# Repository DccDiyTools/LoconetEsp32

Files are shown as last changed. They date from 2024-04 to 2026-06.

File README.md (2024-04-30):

# LoconetEsp32
Esp32 Loconet Interface
# LocoBuffer from LocoLinx32U4

Board for use wiht the [https://github.com/mrrwa/LocoNet/tree/master/examples/LocoLinx32U4] code, there is a copy on this repository for platform.io .

# 0.0.1
- [x] USB
- [x] Loconet
- [x] Leds loconet
- [x] ESP32
- [ ] Btn Reset

# 0.0.X
- [] Loconet Power 
- [] Loconet Master
- [] USB-C
- [] Non-Inv TX
- [] SD
- [] BTN AP
- [] Led Wifi RGB

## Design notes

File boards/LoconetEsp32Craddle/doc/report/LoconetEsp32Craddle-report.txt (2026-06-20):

# PCB

Board size: 95.0x71.0 mm (3.74x2.8 inches)

- This is the size of the rectangle that contains the board
- Thickness: 1.6 mm (63 mils)
- Material: FR4
- Finish: None
- Layers: 4
- Copper thickness: 35 µm

Solder mask: TOP / BOTTOM

- Color: Green

Silk screen: TOP / BOTTOM

- Color: White

Stackup:

| Name | Type | Color | Thickness [µm]| Material | Er | Loss tan |
|---|---|---|---|---|---|---|
| F.SilkS | Top Silk Screen | | | | | |
| F.Paste | Top Solder Paste | | | | | |
| F.Mask | Top Solder Mask | | 10 | | | |
| F.Cu | copper | | 35 | | | |
| dielectric 1 | core | | 480 | FR4 | 4.5 | 0.020 |
| In1.Cu | copper | | 35 | | | |
| dielectric 2 | prepreg | | 480 | FR4 | 4.5 | 0.020 |
| In2.Cu | copper | | 35 | | | |
| dielectric 3 | core | | 480 | FR4 | 4.5 | 0.020 |
| B.Cu | copper | | 35 | | | |
| B.Mask | Bottom Solder Mask | | 10 | | | |
| B.Paste | Bottom Solder Paste  | | | | | |
| B.SilkS | Bottom Silk Screen | | | | | |

# Important sizes

Clearance: 0.2 mm (8 mils)

Track width: 0.25 mm (10 mils)

- By design rules: 0.2 mm (8 mils)

Drill: 0.5 mm (20 mils)

- Vias: 0.5 mm (20 mils) [Design: 0.3 mm (12 mils)]
- Pads: 0.9 mm (35 mils)
- The above values are real drill sizes, they add 0.1 mm (4 mils) to plated holes (PTH)

Via: 0.8/0.4 mm (31/16 mils)

- By design rules: 0.2/0.2 mm (8/8 mils)
- Micro via: yes [0.2/0.1 mm (8/4 mils)]
- Buried/blind via: yes
- Total: 22 (thru: 22 buried/blind: 0 micro: 0)

Outer Annular Ring: 0.15 mm (6 mils)

- By design rules: 0.15 mm (6 mils)

Eurocircuits class: 4B
- Using min drill 0.5 mm for an OAR of 0.15 mm

# General stats

Components count: (SMD/THT)

- Top: 43/8 (SMD + THT)
- Bottom: 0/2 (THT)

Defined tracks:

Used tracks:

- 0.25 mm (10 mils) (153) defined: no
- 0.4 mm (16 mils) (73) defined: no

Defined vias:

Used vias:

- 0.8/0.4 mm (31/16 mils) (Count: 22, Aspect: 2.0 A) defined: no

Holes (excluding vias):

- 0.8 mm (31 mils) (38)
- 0.89 mm (35 mils) (12)
- 1.0 mm (39 mils) (4)
- 3.2 mm (126 mils) (4)
- 3.45 mm (136 mils) (4)

Oval holes:

Drill tools (including vias and computing adjusts and rounding):

- 0.5 mm (20 mils) (22)
- 0.9 mm (35 mils) (38)
- 1.0 mm (39 mils) (12)
- 1.1 mm (43 mils) (4)
- 3.3 mm (130 mils) (4)
- 3.45 mm (136 mils) (4)

Solder paste stats:

Using a paste with 87.75 % alloy, that has an specific gravity for the alloy of 7.4 g/cm³
and 1.0 g/cm³ for the flux. This paste has an specific gravity of  4.15 g/cm³.

The stencil thickness is  0.12 mm.

| Side | Pads with paste | Area [mm²] | Paste [g] |
|---|---|---|---|
| Total  | 106 | 339.67 | 1.69 |

Note: this is just an approximation to the theoretical value. Margins of the solder mask and waste aren't computed.

# Schematic

Exports the Schematic to the most common exhange format. Suitable for printing. page 1

Exports the Schematic to the most common exhange format. Suitable for printing. page 2

Exports the Schematic to the most common exhange format. Suitable for printing. page 3

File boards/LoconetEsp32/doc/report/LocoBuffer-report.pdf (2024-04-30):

## PCB

Board size: 75.0x50.0 mm (2.95x1.97 inches)

- This is the size of the rectangle that contains the board
- Thickness: 1.6 mm (63 mils)
- Material: FR4
- Finish: None
- Layers: 4
- Copper thickness: 35 µm

Solder mask: TOP / BOTTOM

- Color: Green

Silk screen: TOP / BOTTOM

- Color: White

Stackup:

Name | Type | Color | Thickness | Material | Epsilon_r | Loss tangent
F.SilkS | Top Silk Screen
F.Paste | Top Solder Paste
F.Mask | Top Solder Mask | | 10
F.Cu | copper | | 35
dielectric 1 | core | | 480 | FR4 | 4.5 | 0.020
In1.Cu | copper | | 35
dielectric 2 | prepreg | | 480 | FR4 | 4.5 | 0.020
In2.Cu | copper | | 35
dielectric 3 | core | | 480 | FR4 | 4.5 | 0.020
B.Cu | copper | | 35
B.Mask | Bottom Solder Mask | | 10
B.Paste | Bottom Solder Paste
B.SilkS | Bottom Silk Screen

## Important sizes

Clearance: 0.2 mm (8 mils)

Track width: 0.2 mm (8 mils)

- By design rules: 0.2 mm (8 mils)

Drill: 0.3 mm (12 mils)

- Vias: 0.5 mm (20 mils) [Design: 0.3 mm (12 mils)]
- Pads: 0.3 mm (12 mils)

1

- The above values are real drill sizes, they add 0.1 mm (4 mils) to plated holes (PTH)

Via: 0.8/0.4 mm (31/16 mils)

- By design rules: 0.2/0.2 mm (8/8 mils)
- Micro via: yes [0.2/0.1 mm (8/4 mils)]
- Buried/blind via: yes
- Total: 28 (thru: 28 buried/blind: 0 micro: 0)

Outer Annular Ring: 0.15 mm (6 mils)

- By design rules: 0.15 mm (6 mils)

Eurocircuits class: 4D - Using min drill 0.3 mm for an OAR of 0.15 mm

## General stats

Components count: (SMD/THT)

- Top: 46/2 (SMD + THT)
- Bottom: 0/0 (NONE)

Defined tracks:

Used tracks:

- 0.2 mm (8 mils) (32) defined: no
- 0.25 mm (10 mils) (218) defined: no

Defined vias:

Used vias:

- 0.8/0.4 mm (31/16 mils) (Count: 28, Aspect: 2.0 A) defined: no

Holes (excluding vias):

- 0.2 mm (8 mils) (12)
- 0.89 mm (35 mils) (12)
- 3.2 mm (126 mils) (4)
- 3.45 mm (136 mils) (4)

Oval holes:

- 0.5x1.2 mm (20x47 mils) (2)

Drill tools (including vias and computing adjusts and rounding):

- 0.3 mm (12 mils) (12)
- 0.5 mm (20 mils) (28)
- 0.6 mm (24 mils) (2)
- 1.0 mm (39 mils) (12)
- 3.3 mm (130 mils) (4)

2

- 3.45 mm (136 mils) (4)

3

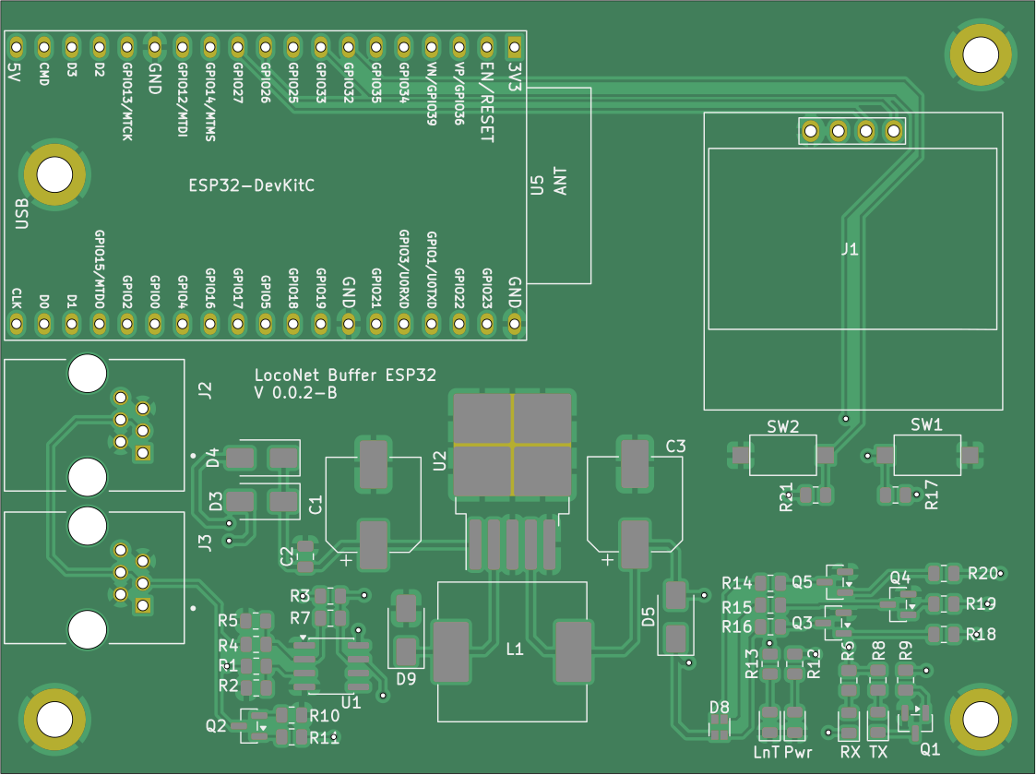
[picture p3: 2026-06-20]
boards/LoconetEsp32Craddle/doc/LoconetEsp32Craddle-top.png

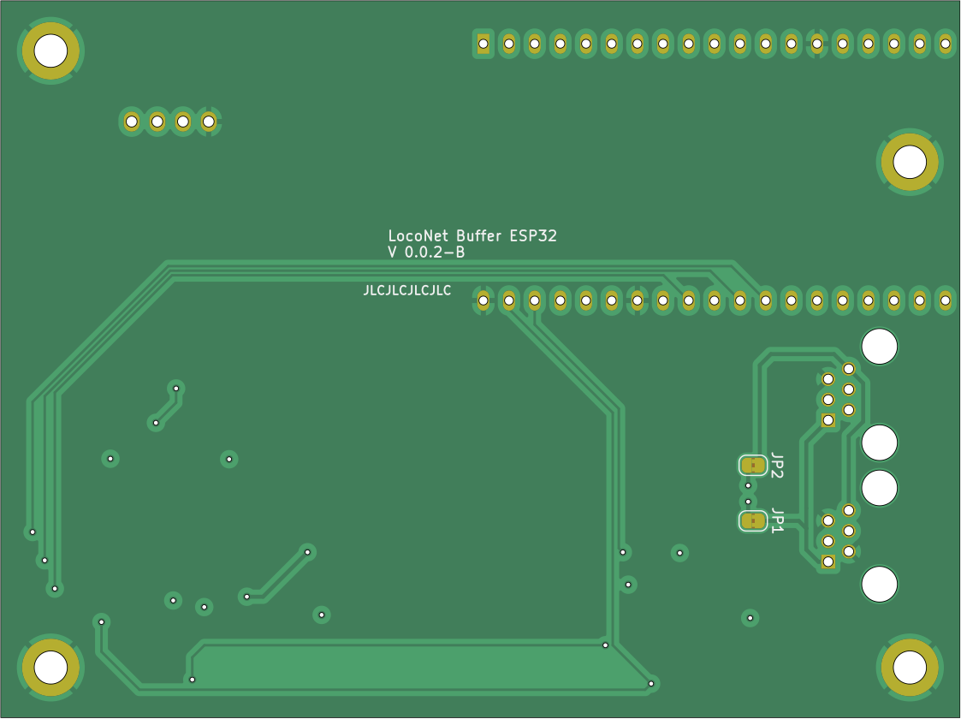
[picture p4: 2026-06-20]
boards/LoconetEsp32Craddle/doc/LoconetEsp32Craddle-bottom.png

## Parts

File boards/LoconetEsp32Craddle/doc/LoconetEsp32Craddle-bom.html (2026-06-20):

 | Bill of Materials
 | Schematic: LoconetEsp32Craddle Variant: default Revision: 0.0.1 Date: 2023-07-17 KiCad Version: 10.0.1-10.0.1~ubuntu25.10.1 | Component Groups: 24 Component Count: 47 (43 SMD/ 4 THT) (per PCB) Fitted Components: 47 (43 SMD/ 4 THT) (per PCB) Number of PCBs: 1 Total Components: 47 (for 1 PCBs)
Row | Description | Part | References | Value | Footprint | Quantity Per PCB | Status | Datasheet | LCSC | Sim.Pins | Sim.Device
1 |  | C | C2 | 100nf | C_0805_2012Metric | 1 |  |  | C282732
2 |  | C_Polarized | C1 C3 | 220uF | CP_Elec_8x10.5 | 2 |  |  | C131124
3 |  | B330 | D9 | B330A | D_SMA | 1 |  | http://www.jameco.com/Jameco/Products/ProdDS/1538777.pdf | C110485
4 | Light emitting diode | LED | D1 D2 D6 D7 | LED | LED_0805_2012Metric | 4 |  |  | C2296 | 1=K 2=A
5 |  | LED_RGBA | D8 | LTST-C19HE1WT | LED_LiteOn_LTST-C19HE1WT | 1 |  |  | C458749
6 |  | D | D3 D4 D5 | SS24A | D_SMA | 3 |  |  | C95872 | 1=K 2=A | D
7 | RJ connector, 6P6C (6 positions 6 connected) | RJ12 | J2 J3 | RJ12 | RJ12_AMPHENOL_RJE0166001 | 2
8 | SSD1306 OLED module, 0.91 inch, 128x32, I2C | ER_OLEDM0.91_1x-I2C | J1 | SD1306 I2C/Oled | ER_OLEDM0.91_1x-I2C-128x64OLED | 1 |  | https://www.buydisplay.com/download/manual/ER-OLEDM0.91-1_Datasheet.pdf
9 |  | L | L1 | 100uH | L_Sunlord_MWSA1206S-101 | 1 |  |  | C408533
10 | 0.115A Id, 60V Vds, N-Channel MOSFET, SOT-23 | 2N7002 | Q3 Q4 Q5 | 2N7002 | SOT-23 | 3 |  | https://www.onsemi.com/pub/Collateral/NDS7002A-D.PDF | C8545
11 | General Purpose NPN Transistor, 1.5A Ic, 25V Vce, SOT-23 | SS8050 | Q1 Q2 | SS8050 | SOT-23 | 2 |  | http://www.secosgmbh.com/datasheet/products/SSMPTransistor/SOT-23/SS8050.pdf | C2150 | 1=B 2=E 3=C | NPN
12 |  | R | R10 | 47 | R_0805_2012Metric | 1 |  |  | C17714
13 |  | R | R6 R8 R12 R13 R14 R15 R16 | 470 | R_0805_2012Metric | 7 |  |  | C17710
14 |  | R | R3 R18 R19 R20 | 1K | R_0805_2012Metric | 4 |  |  | C17513
15 |  | R | R9 R11 | 4.7K | R_0805_2012Metric | 2 |  |  | C229219
16 |  | R | R2 | 22K | R_0805_2012Metric | 1 |  |  | C17560
17 |  | R | R4 | 47K | R_0805_2012Metric | 1 |  |  | C17713
18 |  | R | R5 | 150K | R_0805_2012Metric | 1 |  |  | C17470
19 |  | R | R7 | 220K | R_0805_2012Metric | 1 |  |  | C17556
20 |  | R | R1 R17 R21 | 10K (5%) | R_0805_2012Metric | 3 |  |  | C17414
21 |  | SW_Push | SW1 SW2 | SW_Push | SW_SPST_CK_RS282G05A3 | 2
22 | Development Kit | ESP32-DevKitC | U5 | ESP32-DevKitC | ESP32-DevKitC | 1 |  | https://docs.espressif.com/projects/esp-idf/zh_CN/latest/esp32/hw-reference/esp32/get-started-devkitc.html
23 |  | LM2576S-5 | U2 | LM2576S-5 | TO-263-5_TabPin3 | 1 |  | http://www.ti.com/lit/ds/symlink/lm2576.pdf | C194472
24 |  | LM311 | U1 | LM311 | SOIC-8_3.9x4.9mm_P1.27mm | 1 |  | http://www.ti.com/lit/ds/symlink/lm311.pdf | C12597
Color reference for columns:
KiCad Fields (default)
Generated Fields
User Fields
Empty Fields

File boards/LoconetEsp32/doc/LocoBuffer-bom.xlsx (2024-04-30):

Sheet: BoM
 |  | Bill of Materials
 |  | Schematic: | LocoBuffer | Component Groups: | 27
 |  | Variant: | default | Component Count: | 48 (46 SMD/ 2 THT)
 |  | Revision: |  | Fitted Components: | 48 (46 SMD/ 2 THT)
 |  | Date: | 2023-06-21_17-03-44 | Number of PCBs: | 1
 |  | KiCad Version: | 7.0.5.1-1-g8f565ef7f0-dirty-deb11 | Total Components: | 48
Row | Description | Part | References | Value | Footprint | Quantity Per PCB | Status | Datasheet | LCSC | PARTREV | MANUFACTURER | MAXIMUM_PACKAGE_HEIGHT | STANDARD
1 | Unpolarized capacitor | C | C4 C5 C6 C7 | 0.1uF/50V(10%) | C_0805_2012Metric | 4 |  | ~ | C49678
2 | Unpolarized capacitor | C | C1 C2 | 22uf/10V/20% | C_0805_2012Metric | 2 |  | ~ | C45783
3 | Unpolarized capacitor | C | C3 | 4.7uF/6.3V(10%) | C_0805_2012Metric | 1 |  | ~ | C1779
4 | Schottky diode | D_Schottky | D3 | BAT760-7 | D_SOD-323 | 1 |  | ~ | C124187
5 | Light emitting diode | LED | D1 D2 D7 | LED | LED_0805_2012Metric | 3 |  | ~ | C2296
6 | Bidirectional transient-voltage-suppression diode | D_TVS | D4 D5 D6 | LESD5D5.0CT1G | D_SOD-523 | 3 |  | ~ | C383211
7 |  | 10118193-0001LF | J1 | 10118193-0001LF | AMPHENOL_10118193-0001LF | 1 |  | ~ | C132562 | E | Amphenol FCI | 2.55 mm | Manufacturer Recommendations
8 | RJ connector, 6P6C (6 positions 6 connected) | RJ12 | J2 J3 | RJ12 | AMPHENOL_RJE0166001 | 2 |  | ~
9 | NPN transistor, base/emitter/collector | Q_NPN_BEC | Q1 Q2 Q3 Q4 | SS8050 | SOT-23 | 4 |  | ~ | C2150
10 | Resistor | R | R10 | 47 | R_0805_2012Metric | 1 |  | ~ | C17714
11 | Resistor | R | R6 R8 | 470 | R_0805_2012Metric | 2 |  | ~ | C17710
12 | Resistor | R | R3 | 1K | R_0805_2012Metric | 1 |  | ~ | C17513
13 | Resistor | R | R12 R19 | 2K 5% | R_0805_2012Metric | 2 |  | ~ | C212449
14 | Resistor | R | R9 R11 | 4.7K | R_0805_2012Metric | 2 |  | ~ | C229219
15 | Resistor | R | R2 | 22K | R_0805_2012Metric | 1 |  | ~ | C17560
16 | Resistor | R | R4 | 47K | R_0805_2012Metric | 1 |  | ~ | C17713
17 | Resistor | R | R5 | 150K | R_0805_2012Metric | 1 |  | ~ | C17470
18 | Resistor | R | R7 | 220K | R_0805_2012Metric | 1 |  | ~ | C17556
19 | Resistor | R | R13 R14 | 0 (5%) | R_0805_2012Metric | 2 |  | ~ | C2936632
20 | Resistor | R | R1 R15 R16 R20 R21 | 10K (5%) | R_0805_2012Metric | 5 |  | ~ | C17414
21 | Resistor | R | R17 | 22K1 (5%) | R_0805_2012Metric | 1 |  | ~ | C153391
22 | Resistor | R | R18 | 47K5 (5%) | R_0805_2012Metric | 1 |  | ~ | C245335
23 | Push button switch, generic, two pins | SW_Push | SW1 SW2 | SW_Push | SW_Push_1P1T_XKB_TS-1187A | 2 |  | ~
24 | 1A Low Dropout regulator, positive, 3.3V fixed output, SOT-223 | AMS1117-3.3 | U3 | AMS1117-3.3 | SOT-223-3_TabPin2 | 1 |  | http://www.advanced-monolithic.com/pdf/ds1117.pdf | C6186
25 | USB to UART master bridge, QFN-28 | CP2102N-Axx-xQFN28 | U2 | CP2102N-A01-GQFN28 | QFN-28-1EP_5x5mm_P0.5mm_EP3.35x3.35mm | 1 |  | https://www.silabs.com/documents/public/data-sheets/cp2102n-datasheet.pdf | C964632
26 | RF Module, ESP32-D0WDQ6 SoC, Wi-Fi 802.11b/g/n, Bluetooth, BLE, 32-bit, 2.7-3.6V, onboard antenna, SMD | ESP32-WROOM-32 | U4 | ESP32-WROOM-32 | ESP32-WROOM-32 | 1 |  | https://www.espressif.com/sites/default/files/documentation/esp32-wroom-32_datasheet_en.pdf | C701343
27 | Voltage Comparator, DIP-8/SOIC-8 | LM311 | U1 | LM311 | SOIC-8_3.9x4.9mm_P1.27mm | 1 |  | http://www.ti.com/lit/ds/symlink/lm311.pdf | C12597

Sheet: Colors
KiCad Fields (default)
Generated Fields
User Fields
Empty Fields

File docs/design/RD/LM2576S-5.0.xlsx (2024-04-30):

ID | Name | Designator | Footprint | Quantity | BOM_Supplier | BOM_Supplier Part | BOM_Manufacturer | BOM_Manufacturer Part
1 | 100uH | L1 | IND-SMD_L12.2-W12.2_MS127 | 1 | LCSC | C408533 | Sunlord | MWSA1206S-101MT
2 | LM2576S-5.0/TR | U2 | TO-263-5_L10.6-W9.6-P1.70-LS15.9-BR | 1 | LCSC | C194472 | HGSEMI | LM2576S-5.0/TR
3 | 220uF | C1,C3 | CAP-TH_BD8.0-P3.50-D1.0-FD | 2 | LCSC | C114911 | LCSC | -
4 | 17-21SURC/S530-A3/TR8 | LED1 | LED0805-R-RD | 1 | LCSC | C72037 | EVERLIGHT | 17-21SURC/S530-A3/TR8
5 | JL301-50002U02 | U1,U3 | CONN-TH_2P-P2.54_JL301-50002U02 | 2 | LCSC | C395214 | JILN | JL301-50002U02
6 | B330A-13-F | D2 | SMA_L4.4-W2.8-LS5.4-RD | 1 | LCSC | C110485 | DIODES | B330A-13-F
7 | SS14-TP | D1 | SMA_L4.4-W2.8-LS5.4-RD | 1 | LCSC | C78082 | MCC | SS14-TP
8 | DC005-2.0MM | DC1 | DC-IN-TH_DC005 | 1 | LCSC | C111567 | SOFNG | DC005-2.0MM
9 | 470 | R1 | R0805 | 1 | LCSC | C304484 | RALEC | RAT034700FTP
10 | 100nF | C2 | C0805 | 1 | LCSC | C282732 | CCTC | TCC0805X7R104K500DT

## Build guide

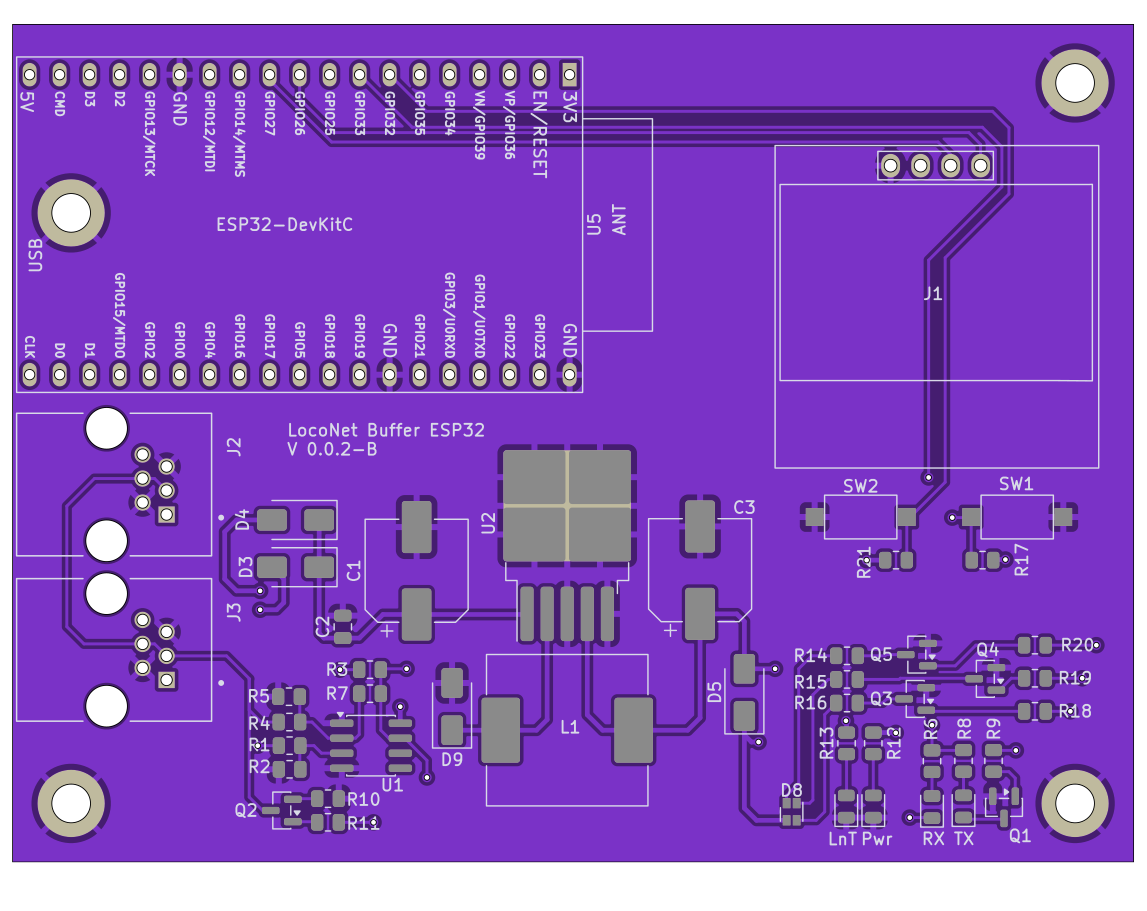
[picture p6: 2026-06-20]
boards/LoconetEsp32Craddle/manual/LoconetEsp32Craddle-top.png

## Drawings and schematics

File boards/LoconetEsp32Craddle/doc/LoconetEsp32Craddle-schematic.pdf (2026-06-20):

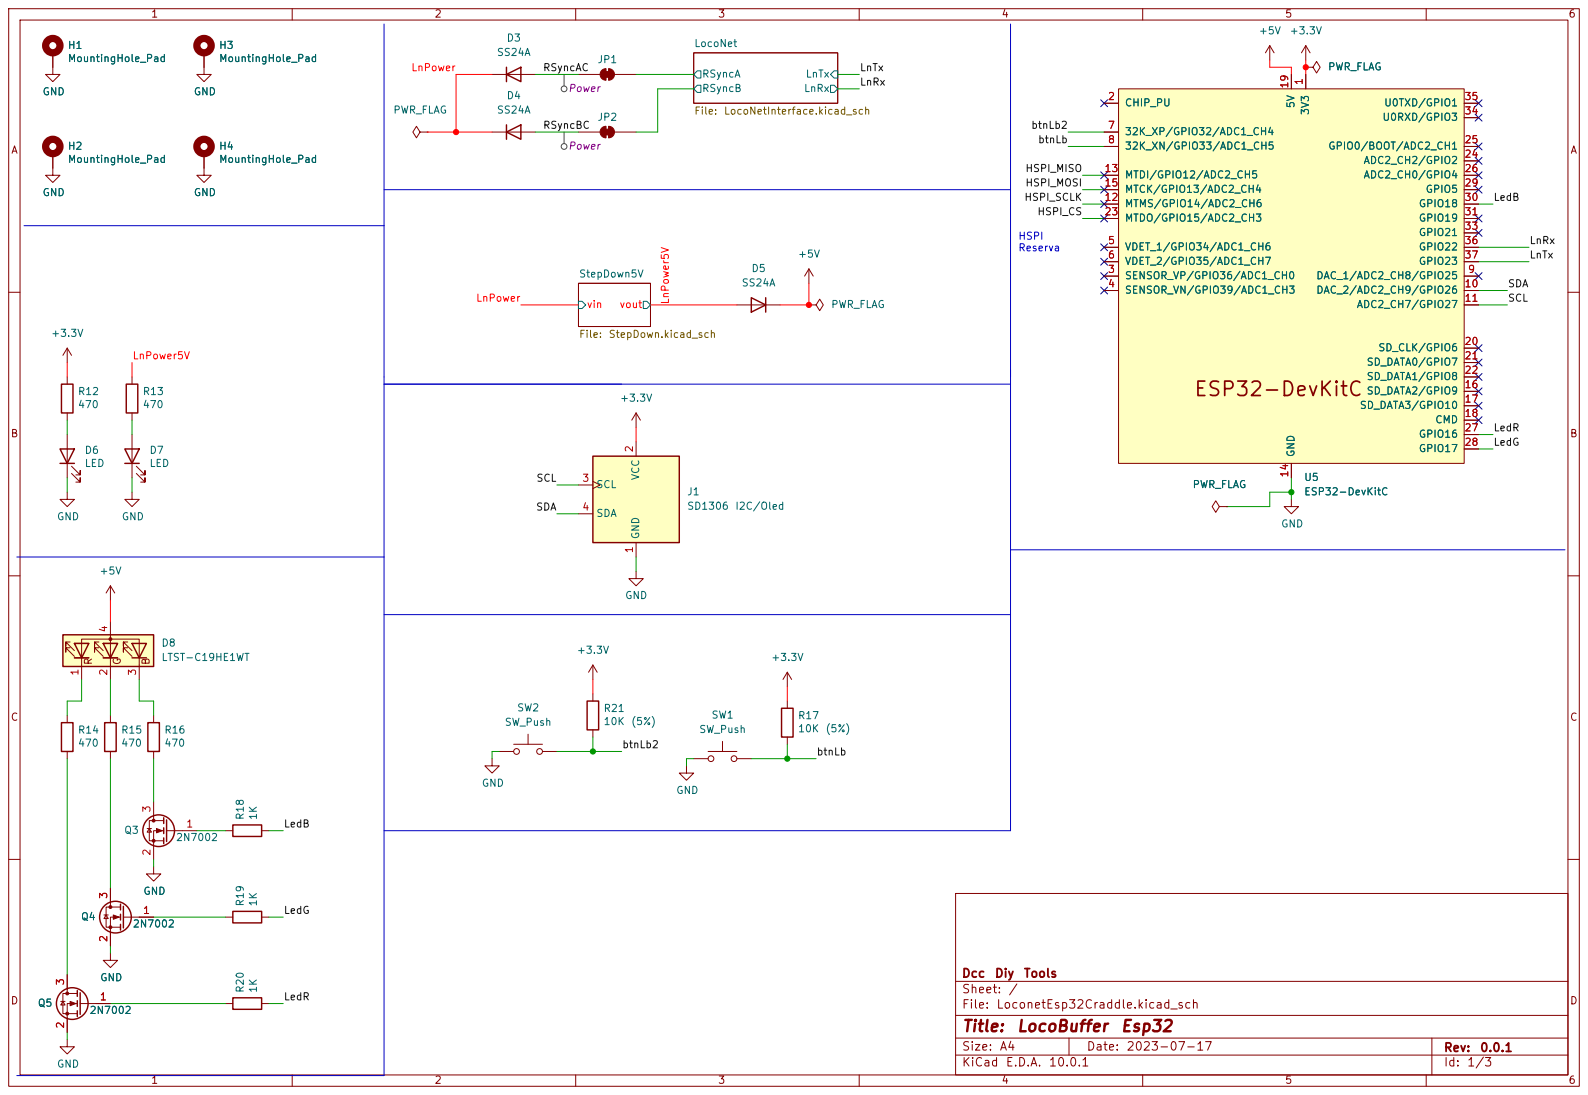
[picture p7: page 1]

Size: A4 | Rev: 0.0.1
KiCad E.D.A. 10.0.1 | Id: 1/3

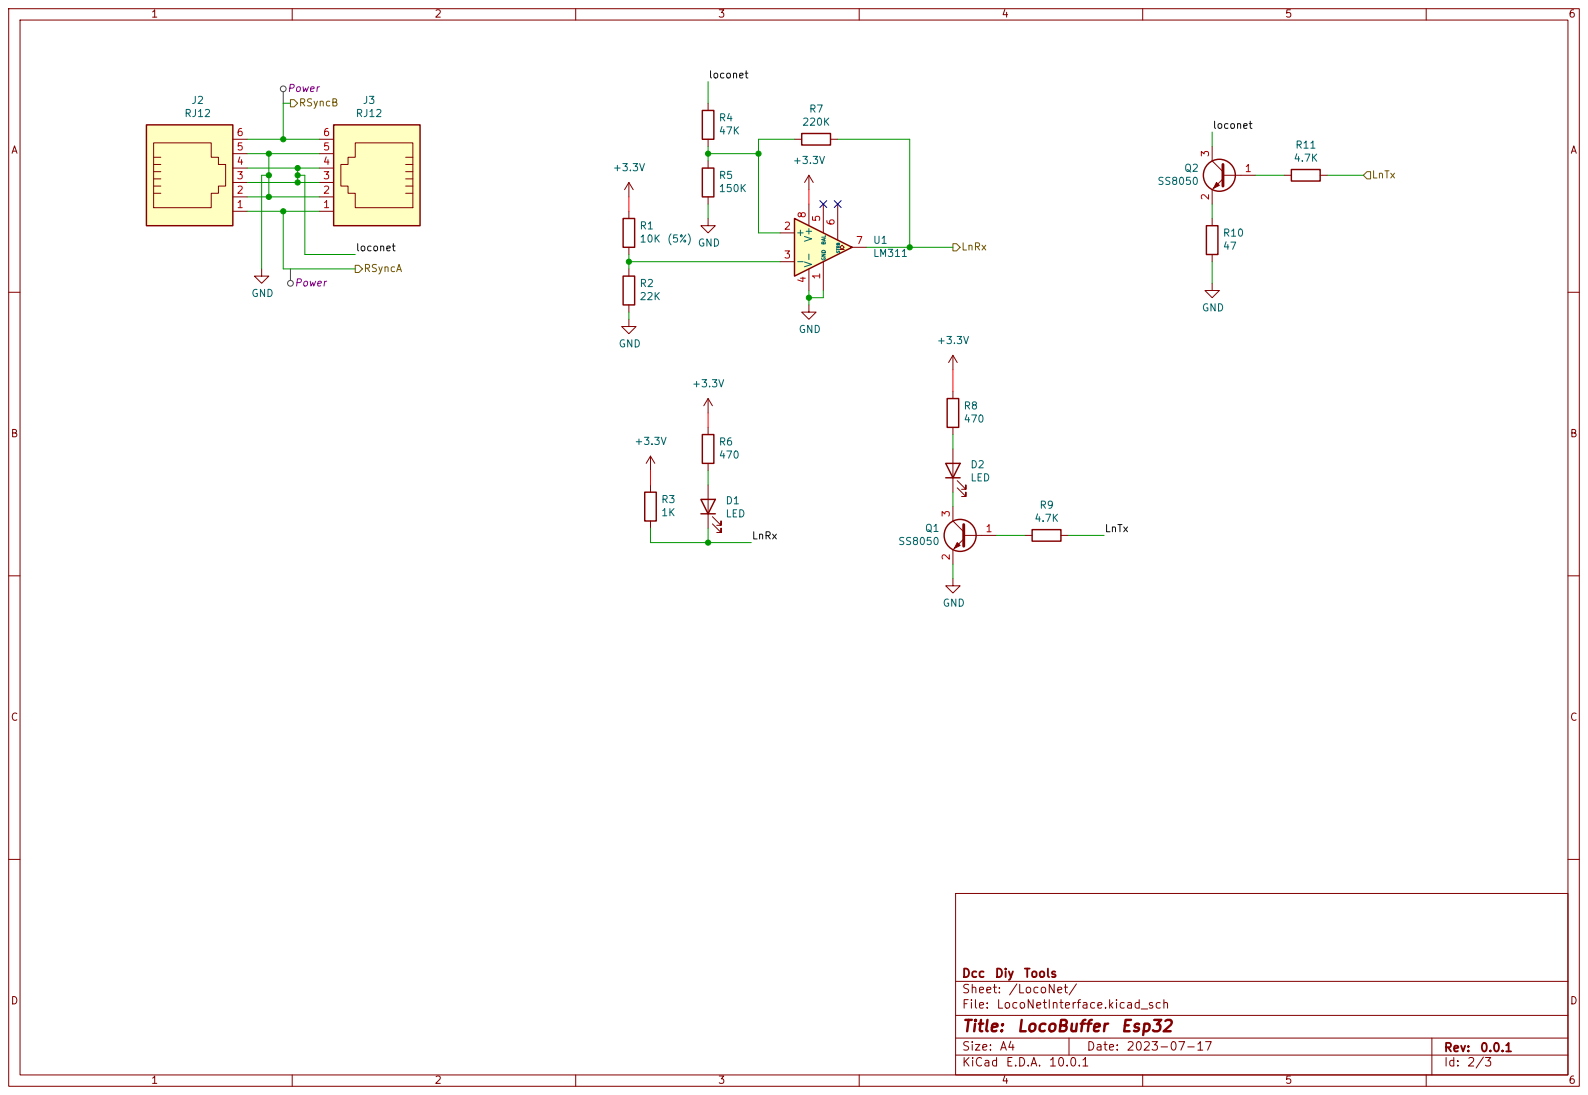
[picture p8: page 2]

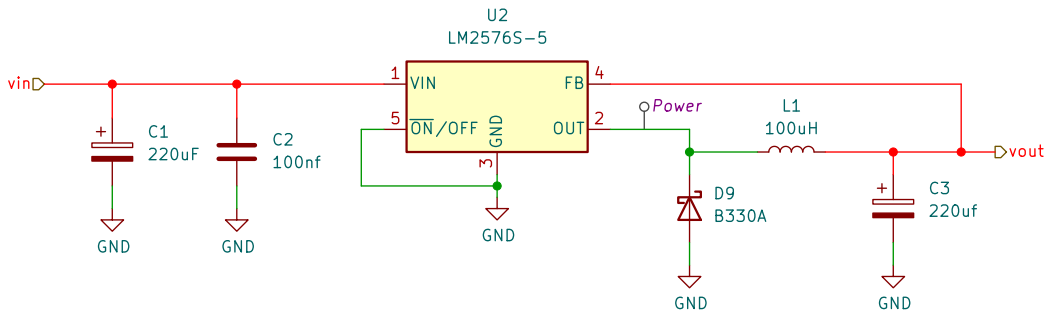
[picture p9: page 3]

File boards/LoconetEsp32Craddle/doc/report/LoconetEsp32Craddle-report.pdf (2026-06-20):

## PCB

Board size: 95.0x71.0 mm (3.74x2.8 inches)

- This is the size of the rectangle that contains the board
- Thickness: 1.6 mm (63 mils)
- Material: FR4
- Finish: None
- Layers: 4
- Copper thickness: 35 µm

Solder mask: TOP / BOTTOM

- Color: Green

Silk screen: TOP / BOTTOM

- Color: White

Stackup:

Name | Type | Color

Thickness
| | [µm] | Material | Er | Loss
| | | | | tan
F.SilkS | Top Silk
| Screen
F.Paste | Top Solder
| Paste
F.Mask | Top Solder
| Mask | 10
F.Cu | copper | 35
dielectric 1 | core | 480 | FR4 | 4.5 | 0.020
In1.Cu | copper | 35
dielectric 2 | prepreg | 480 | FR4 | 4.5 | 0.020
In2.Cu | copper | 35
dielectric 3 | core | 480 | FR4 | 4.5 | 0.020
B.Cu | copper | 35
B.Mask | Bottom
| Solder
| Mask | 10
B.Paste | Bottom
| Solder
| Paste
B.SilkS | Bottom
| Silk Screen

## Important sizes

Clearance: 0.2 mm (8 mils)

1

Track width: 0.25 mm (10 mils)

- By design rules: 0.2 mm (8 mils)

Drill: 0.5 mm (20 mils)

- Vias: 0.5 mm (20 mils) [Design: 0.3 mm (12 mils)]
- Pads: 0.9 mm (35 mils)
- The above values are real drill sizes, they add 0.1 mm (4 mils) to plated holes (PTH)

Via: 0.8/0.4 mm (31/16 mils)

- By design rules: 0.2/0.2 mm (8/8 mils)
- Micro via: yes [0.2/0.1 mm (8/4 mils)]
- Buried/blind via: yes
- Total: 22 (thru: 22 buried/blind: 0 micro: 0)

Outer Annular Ring: 0.15 mm (6 mils)

- By design rules: 0.15 mm (6 mils)

Eurocircuits class: 4B - Using min drill 0.5 mm for an OAR of 0.15 mm

## General stats

Components count: (SMD/THT)

- Top: 43/8 (SMD + THT)
- Bottom: 0/2 (THT)

Defined tracks:

Used tracks:

- 0.25 mm (10 mils) (153) defined: no
- 0.4 mm (16 mils) (73) defined: no

Defined vias:

Used vias:

- 0.8/0.4 mm (31/16 mils) (Count: 22, Aspect: 2.0 A) defined: no

Holes (excluding vias):

- 0.8 mm (31 mils) (38)
- 0.89 mm (35 mils) (12)
- 1.0 mm (39 mils) (4)
- 3.2 mm (126 mils) (4)
- 3.45 mm (136 mils) (4)

Oval holes:

2

Drill tools (including vias and computing adjusts and rounding):

- 0.5 mm (20 mils) (22)
- 0.9 mm (35 mils) (38)
- 1.0 mm (39 mils) (12)
- 1.1 mm (43 mils) (4)
- 3.3 mm (130 mils) (4)
- 3.45 mm (136 mils) (4)

Solder paste stats:

Using a paste with 87.75 % alloy, that has an specific gravity for the alloy of 7.4 g/cm³ and 1.0 g/cm³ for the flux. This paste has an specific gravity of 4.15 g/cm³.

The stencil thickness is 0.12 mm.

Side | Pads with paste | Area [mm²] | Paste [g]
Total | 106 | 339.67 | 1.69

Note: this is just an approximation to the theoretical value. Margins of the solder mask and waste aren’t computed.

## Schematic

3

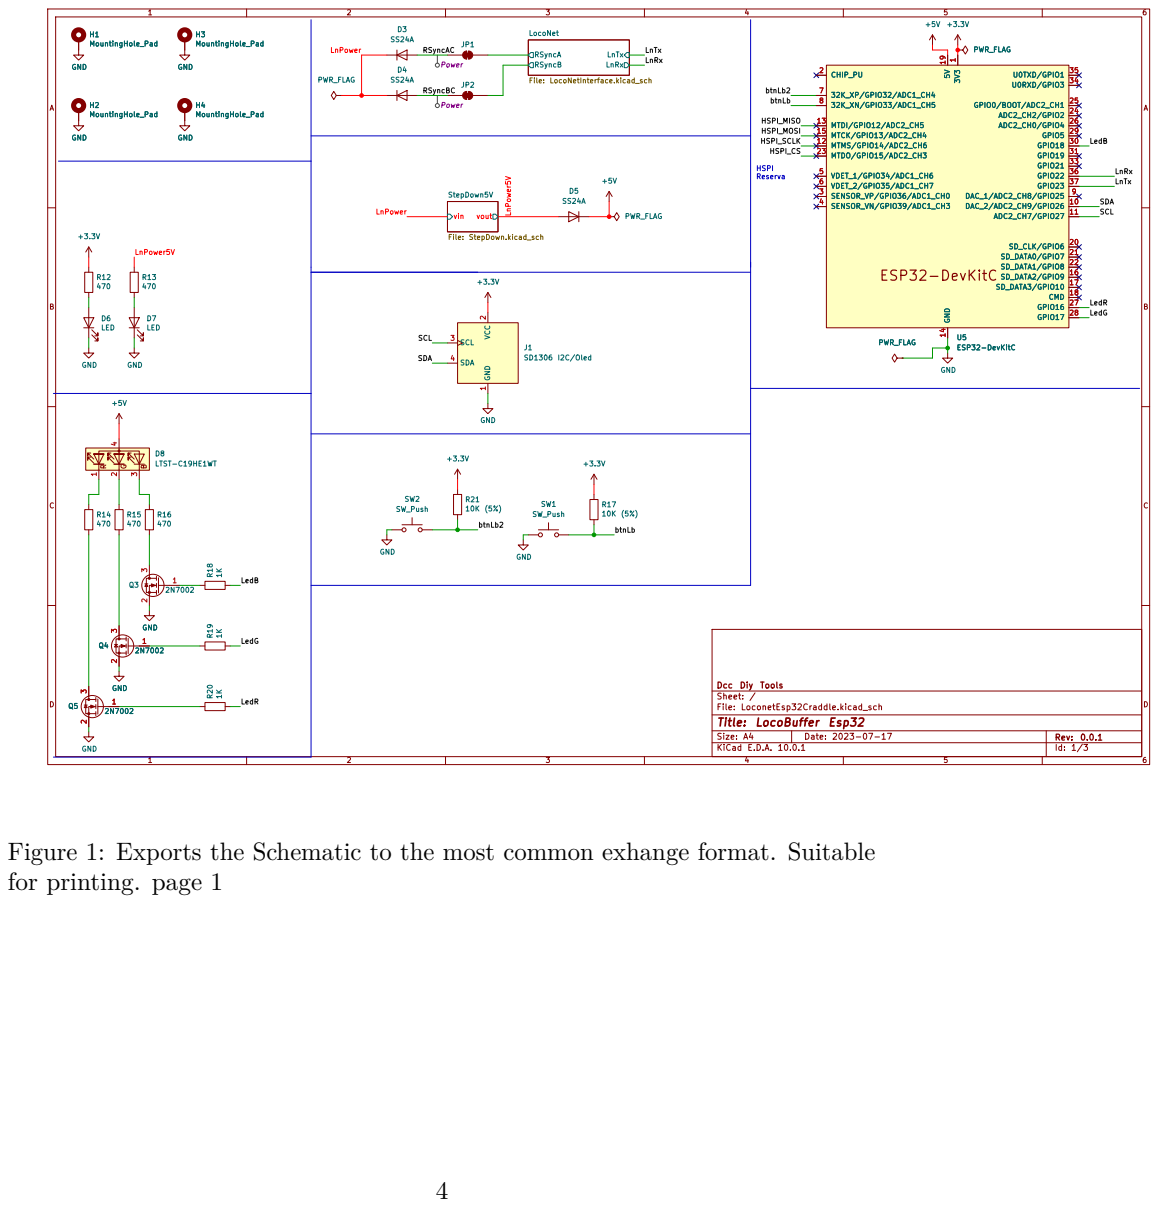
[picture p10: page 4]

LnRx SCL SDA btnLb2 RSyncAC

Figure 1: Exports the Schematic to the most common exhange format. Suitable
for printing. page 1

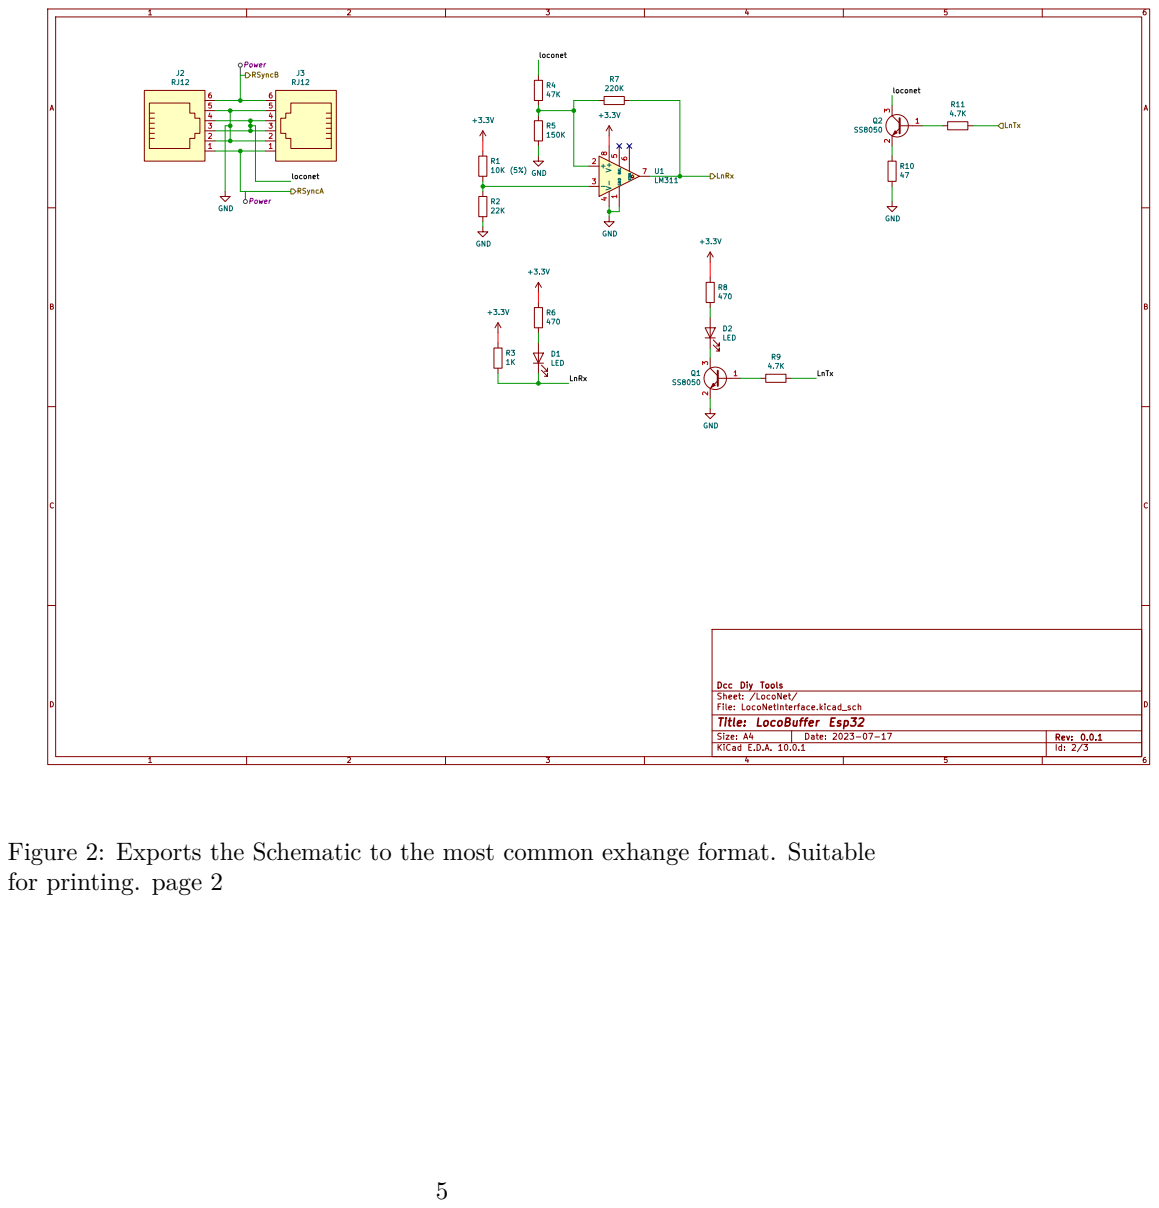
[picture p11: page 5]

Figure 2: Exports the Schematic to the most common exhange format. Suitable
for printing. page 2

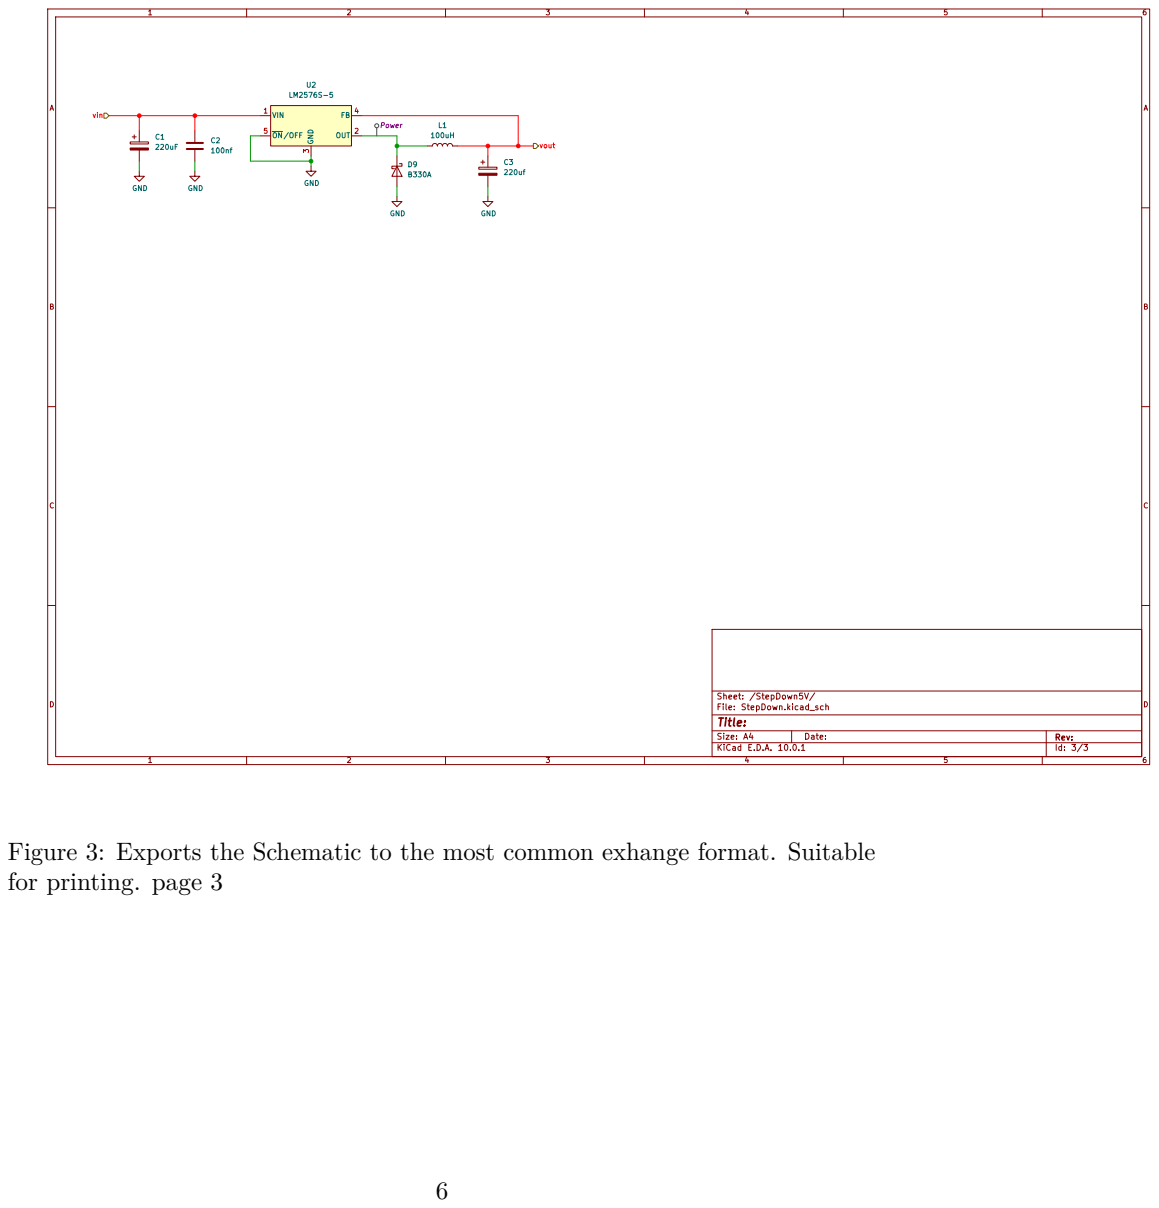
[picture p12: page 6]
D Date:; KiCad E.D.A. 10.0.1; Size: A4; Rev:; Title:; File: StepDown.kicad_sch; Sheet: /StepDown5V/; GND; 220uf GND; VIN 1; OUT 2 GND; FB 4 ON/OFF 5; D9B330A Power vin; vout

Figure 3: Exports the Schematic to the most common exhange format. Suitable
for printing. page 3

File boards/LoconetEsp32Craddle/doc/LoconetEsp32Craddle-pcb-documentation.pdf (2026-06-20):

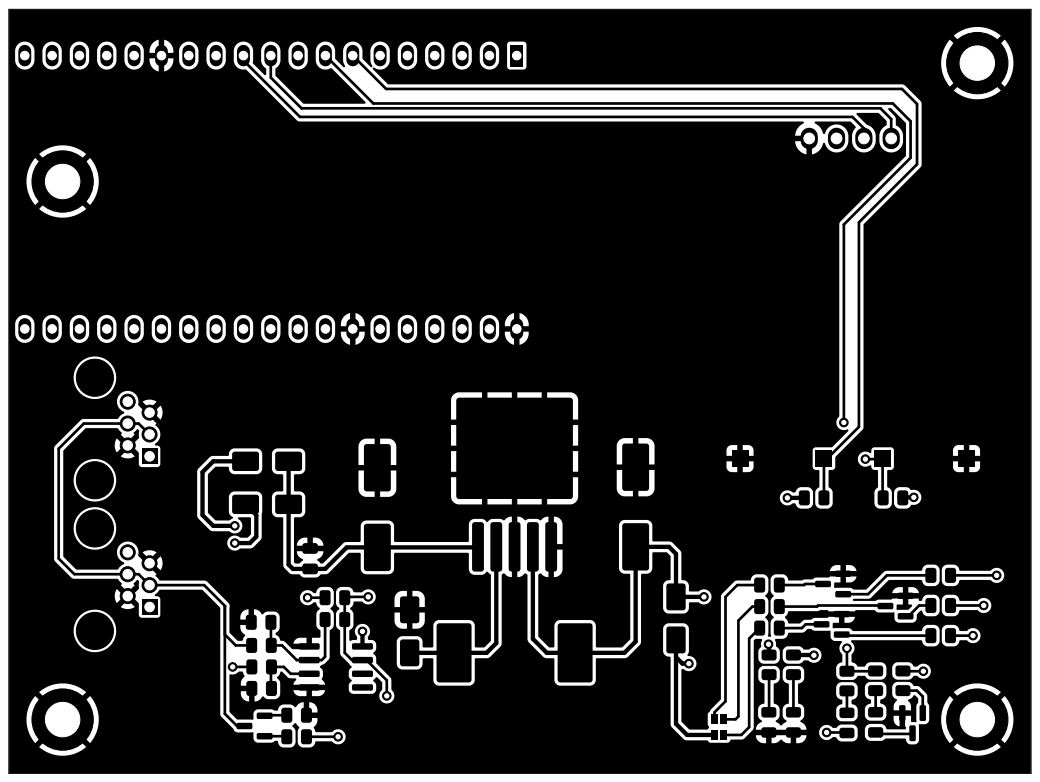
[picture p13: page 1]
D Date: 2023-07-17; ${KICAD_VERSION}; Size: A4; Rev: 0.0.1; Title: LocoBuffer Esp32; File: LoconetEsp32Craddle.kicad_pcb; Sheet:; Dcc Diy Tools

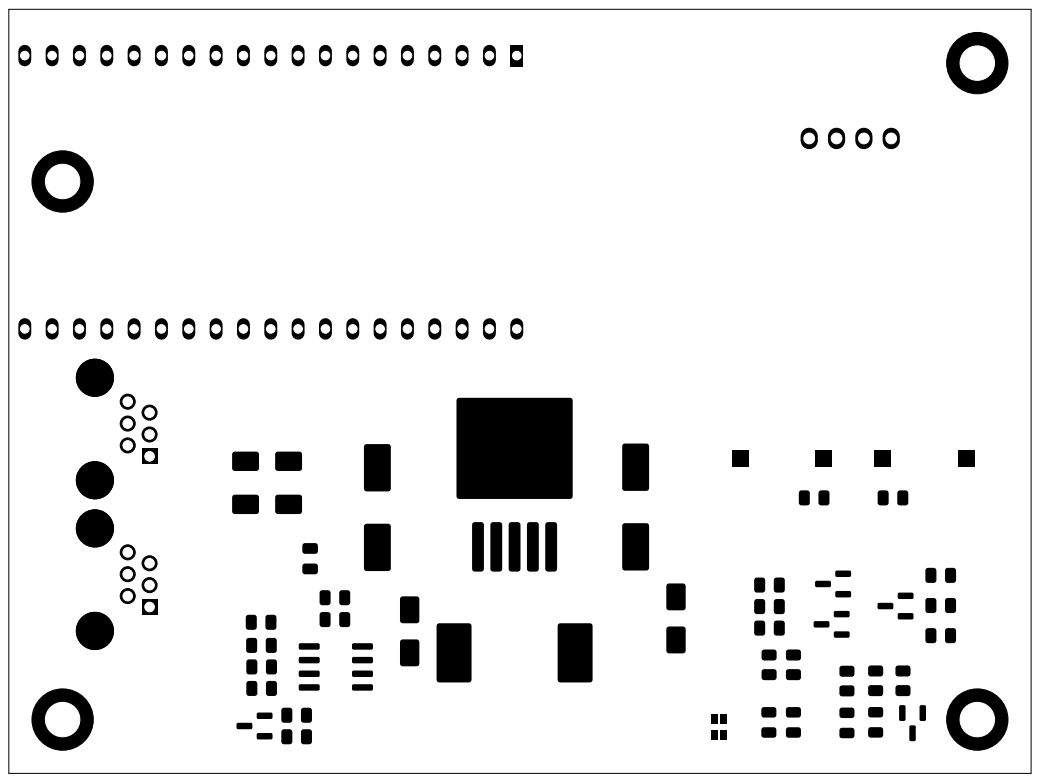
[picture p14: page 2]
D Date: 2023-07-17

Dcc Diy Tools
Sheet:
File: LoconetEsp32Craddle.kicad_pcb
Title: LocoBuffer Esp32

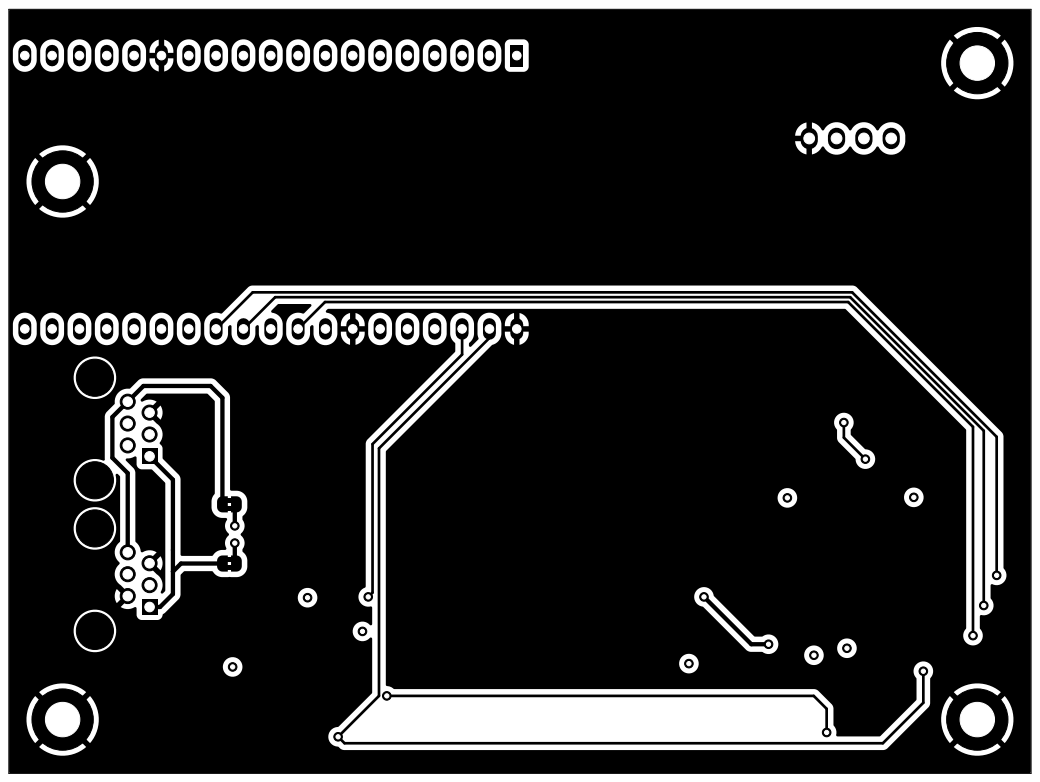
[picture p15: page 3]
D Date: 2023-07-17

Dcc Diy Tools
Sheet:
File: LoconetEsp32Craddle.kicad_pcb
Title: LocoBuffer Esp32

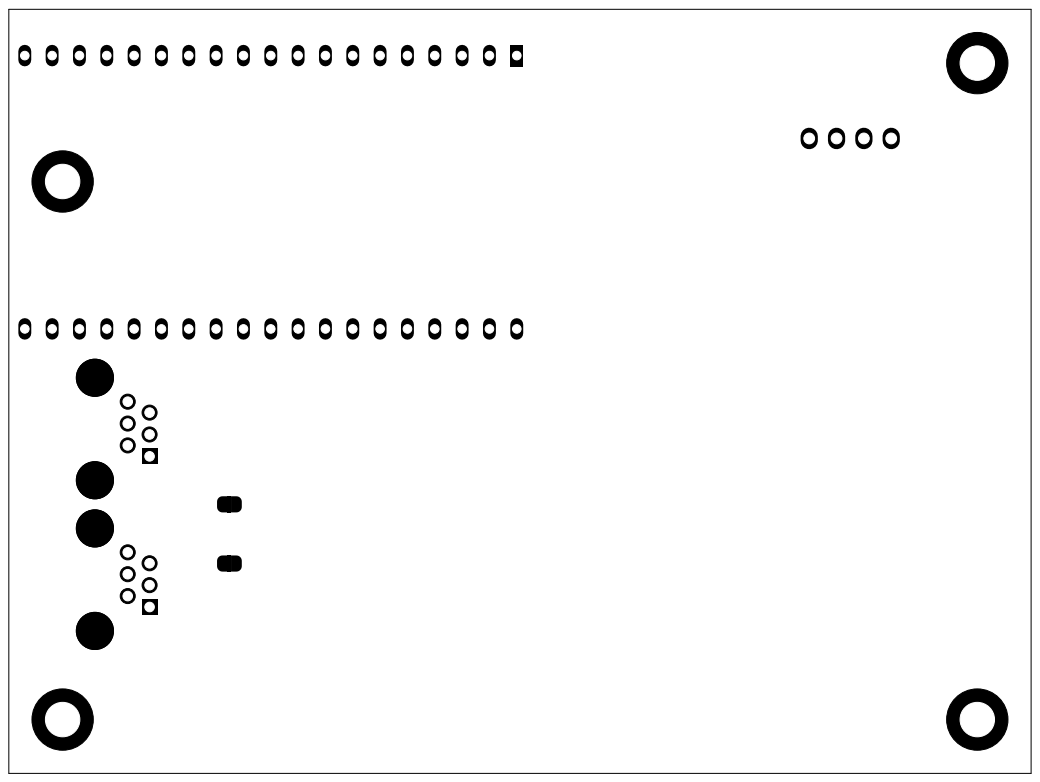
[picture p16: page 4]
D Date: 2023-07-17

Dcc Diy Tools
Sheet:
File: LoconetEsp32Craddle.kicad_pcb
Title: LocoBuffer Esp32

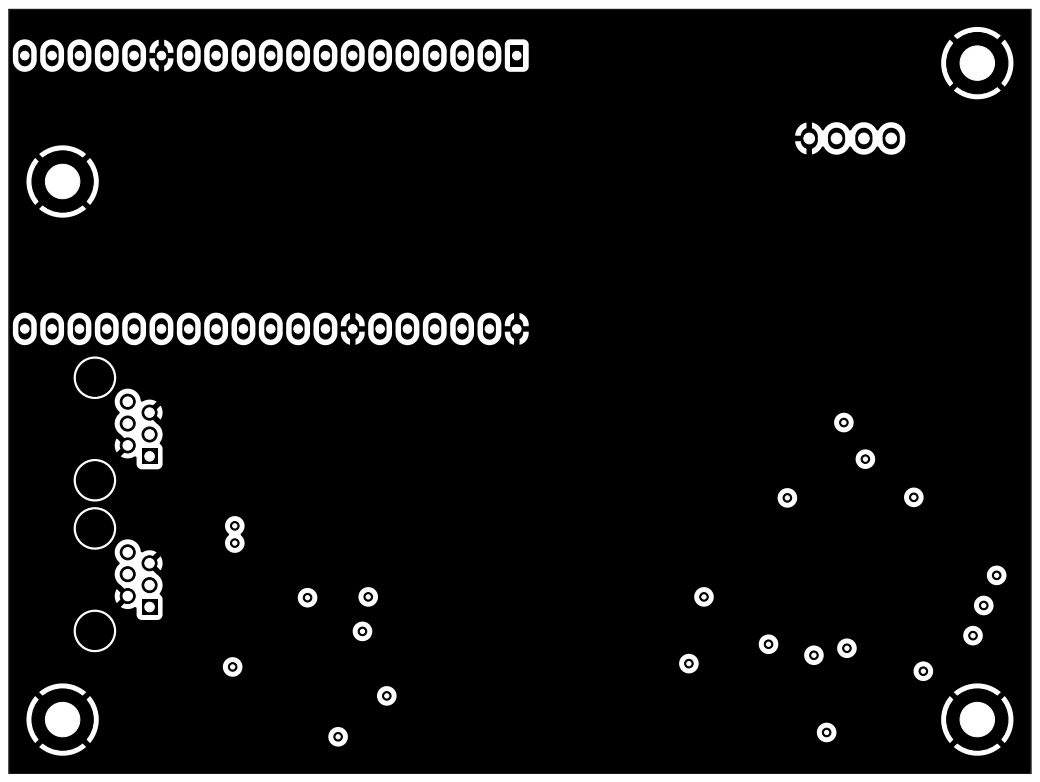
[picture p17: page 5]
D Date: 2023-07-17

Dcc Diy Tools
Sheet:
File: LoconetEsp32Craddle.kicad_pcb
Title: LocoBuffer Esp32

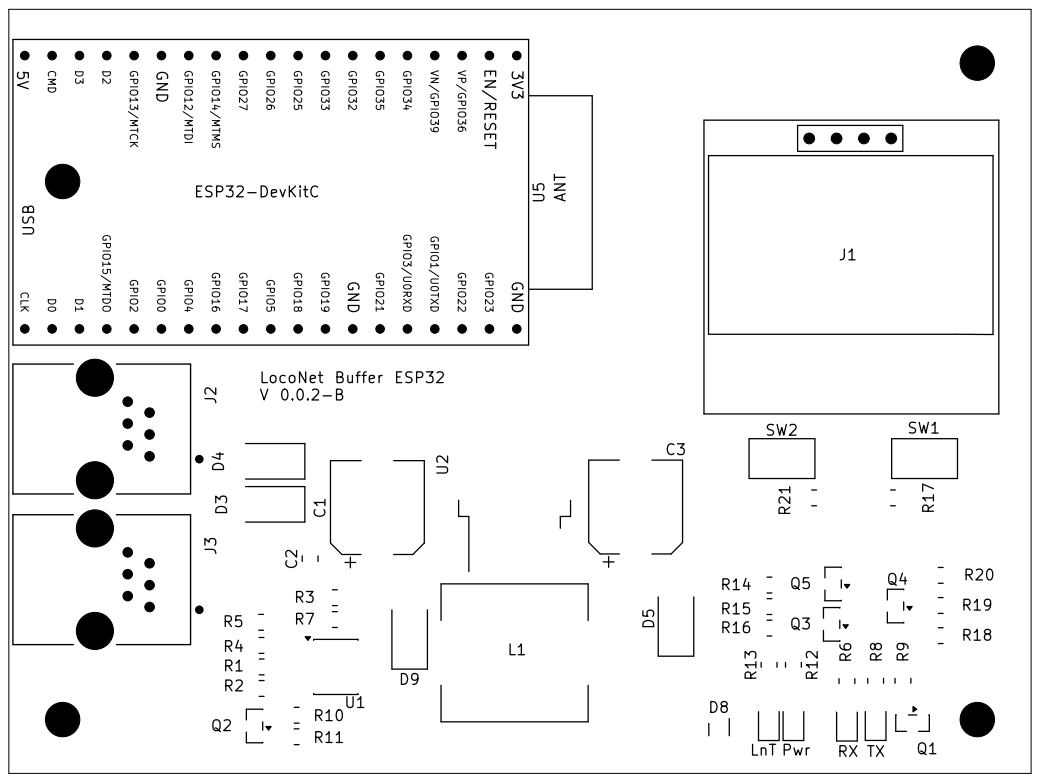
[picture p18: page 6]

D Date: 2023-07-17

Dcc Diy Tools
Sheet:
File: LoconetEsp32Craddle.kicad_pcb
Title: LocoBuffer Esp32

D Date: 2023-07-17

Dcc Diy Tools
Sheet:
File: LoconetEsp32Craddle.kicad_pcb
Title: LocoBuffer Esp32

D Date: 2023-07-17

Dcc Diy Tools
Sheet:
File: LoconetEsp32Craddle.kicad_pcb
Title: LocoBuffer Esp32

Dcc Diy Tools
Sheet:
File: LoconetEsp32Craddle.kicad_pcb
Title: LocoBuffer Esp32

D Date: 2023-07-17

Dcc Diy Tools
Sheet:
File: LoconetEsp32Craddle.kicad_pcb
Title: LocoBuffer Esp32

Dcc Diy Tools
Sheet:
File: LoconetEsp32Craddle.kicad_pcb
Title: LocoBuffer Esp32

D Date: 2023-07-17

Dcc Diy Tools
Sheet:
File: LoconetEsp32Craddle.kicad_pcb
Title: LocoBuffer Esp32

D Date: 2023-07-17

Dcc Diy Tools
Sheet:
File: LoconetEsp32Craddle.kicad_pcb
Title: LocoBuffer Esp32

D Date: 2023-07-17

Dcc Diy Tools
Sheet:
File: LoconetEsp32Craddle.kicad_pcb
Title: LocoBuffer Esp32

Dcc Diy Tools
Sheet:
File: LoconetEsp32Craddle.kicad_pcb
Title: LocoBuffer Esp32

D Date: 2023-07-17

Dcc Diy Tools
Sheet:
File: LoconetEsp32Craddle.kicad_pcb
Title: LocoBuffer Esp32

Dcc Diy Tools
Sheet:
File: LoconetEsp32Craddle.kicad_pcb
Title: LocoBuffer Esp32

D Date: 2023-07-17

Dcc Diy Tools
Sheet:
File: LoconetEsp32Craddle.kicad_pcb
Title: LocoBuffer Esp32

D Date: 2023-07-17

Dcc Diy Tools
Sheet:
File: LoconetEsp32Craddle.kicad_pcb
Title: LocoBuffer Esp32

Dcc Diy Tools
Sheet:
File: LoconetEsp32Craddle.kicad_pcb
Title: LocoBuffer Esp32


Dcc Diy Tools LED D1 RJ12 RJ12

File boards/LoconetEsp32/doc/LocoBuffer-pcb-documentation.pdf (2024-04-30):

D Date: ${KICAD_VERSION} Size: A4; Rev:

Id: 1/1 Title: File: LocoBuffer.kicad_pcb Sheet:

D Date: ${KICAD_VERSION} Size: A4; Rev:

Id: 1/1 Title: File: LocoBuffer.kicad_pcb Sheet:

D Date: ${KICAD_VERSION} Size: A4; Rev:

Id: 1/1 Title: File: LocoBuffer.kicad_pcb Sheet:

D Date: ${KICAD_VERSION} Size: A4; Rev:

Id: 1/1 Title: File: LocoBuffer.kicad_pcb Sheet:

D Date: ${KICAD_VERSION} Size: A4; Rev:

Id: 1/1 Title: File: LocoBuffer.kicad_pcb Sheet:

Id: 1/1 Title: File: LocoBuffer.kicad_pcb Sheet:

Id: 1/1 Title: File: LocoBuffer.kicad_pcb Sheet:

D Date: ${KICAD_VERSION} Size: A4; Rev:

Id: 1/1 Title: File: LocoBuffer.kicad_pcb Sheet:

D Date: ${KICAD_VERSION} Size: A4; Rev:; LocoNet Buffer ESP32 V 0.0.1; JLCJLCJLCJLC

Id: 1/1 Title: File: LocoBuffer.kicad_pcb Sheet:


Id: 1/1 Title: File: LocoBuffer.kicad_pcb Sheet: RX

D Date: ${KICAD_VERSION} Size: A4; Rev:

Id: 1/1 Title: File: LocoBuffer.kicad_pcb Sheet:

D Date: ${KICAD_VERSION} Size: A4; Rev:

Id: 1/1 Title: File: LocoBuffer.kicad_pcb Sheet:

D Date: ${KICAD_VERSION} Size: A4; Rev:

Id: 1/1 Title: File: LocoBuffer.kicad_pcb Sheet:

6 ABCD; ABCD Date: ${KICAD_VERSION} Size: A4; Rev:

Id: 1/1 Title: File: LocoBuffer.kicad_pcb Sheet: KEEP⁻OUT ZONE Antenna

Id: 1/1 Title: File: LocoBuffer.kicad_pcb Sheet:

Id: 1/1 Title: File: LocoBuffer.kicad_pcb Sheet:

D Date: ${KICAD_VERSION} Size: A4; Rev:

Id: 1/1 Title: File: LocoBuffer.kicad_pcb Sheet:

Id: 1/1 Title: File: LocoBuffer.kicad_pcb Sheet:

Id: 1/1 Title: File: LocoBuffer.kicad_pcb Sheet:

D Date: ${KICAD_VERSION} Size: A4; Rev:

Id: 1/1 Title: File: LocoBuffer.kicad_pcb Sheet:

Id: 1/1 Title: File: LocoBuffer.kicad_pcb Sheet:


Id: 1/1 Title: File: LocoBuffer.kicad_pcb Sheet: LEDD¹ RJ12 RJ12

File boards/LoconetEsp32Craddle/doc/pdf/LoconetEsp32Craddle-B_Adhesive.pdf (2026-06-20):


Size: A4 | Rev: 0.0.1
${KICAD_VERSION} | Id: /1

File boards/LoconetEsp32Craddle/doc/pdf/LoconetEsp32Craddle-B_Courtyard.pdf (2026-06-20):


Size: A4 | Rev: 0.0.1
${KICAD_VERSION} | Id: /1

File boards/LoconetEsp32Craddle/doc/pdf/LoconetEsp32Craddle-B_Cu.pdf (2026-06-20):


Size: A4 | Rev: 0.0.1
${KICAD_VERSION} | Id: /1

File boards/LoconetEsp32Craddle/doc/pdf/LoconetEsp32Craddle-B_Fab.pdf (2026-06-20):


Size: A4 | Rev: 0.0.1
${KICAD_VERSION} | Id: /1

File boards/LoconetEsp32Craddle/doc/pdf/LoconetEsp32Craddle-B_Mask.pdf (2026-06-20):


Size: A4 | Rev: 0.0.1
${KICAD_VERSION} | Id: /1

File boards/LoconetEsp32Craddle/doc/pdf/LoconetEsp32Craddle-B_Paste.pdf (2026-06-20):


Size: A4 | Rev: 0.0.1
${KICAD_VERSION} | Id: /1

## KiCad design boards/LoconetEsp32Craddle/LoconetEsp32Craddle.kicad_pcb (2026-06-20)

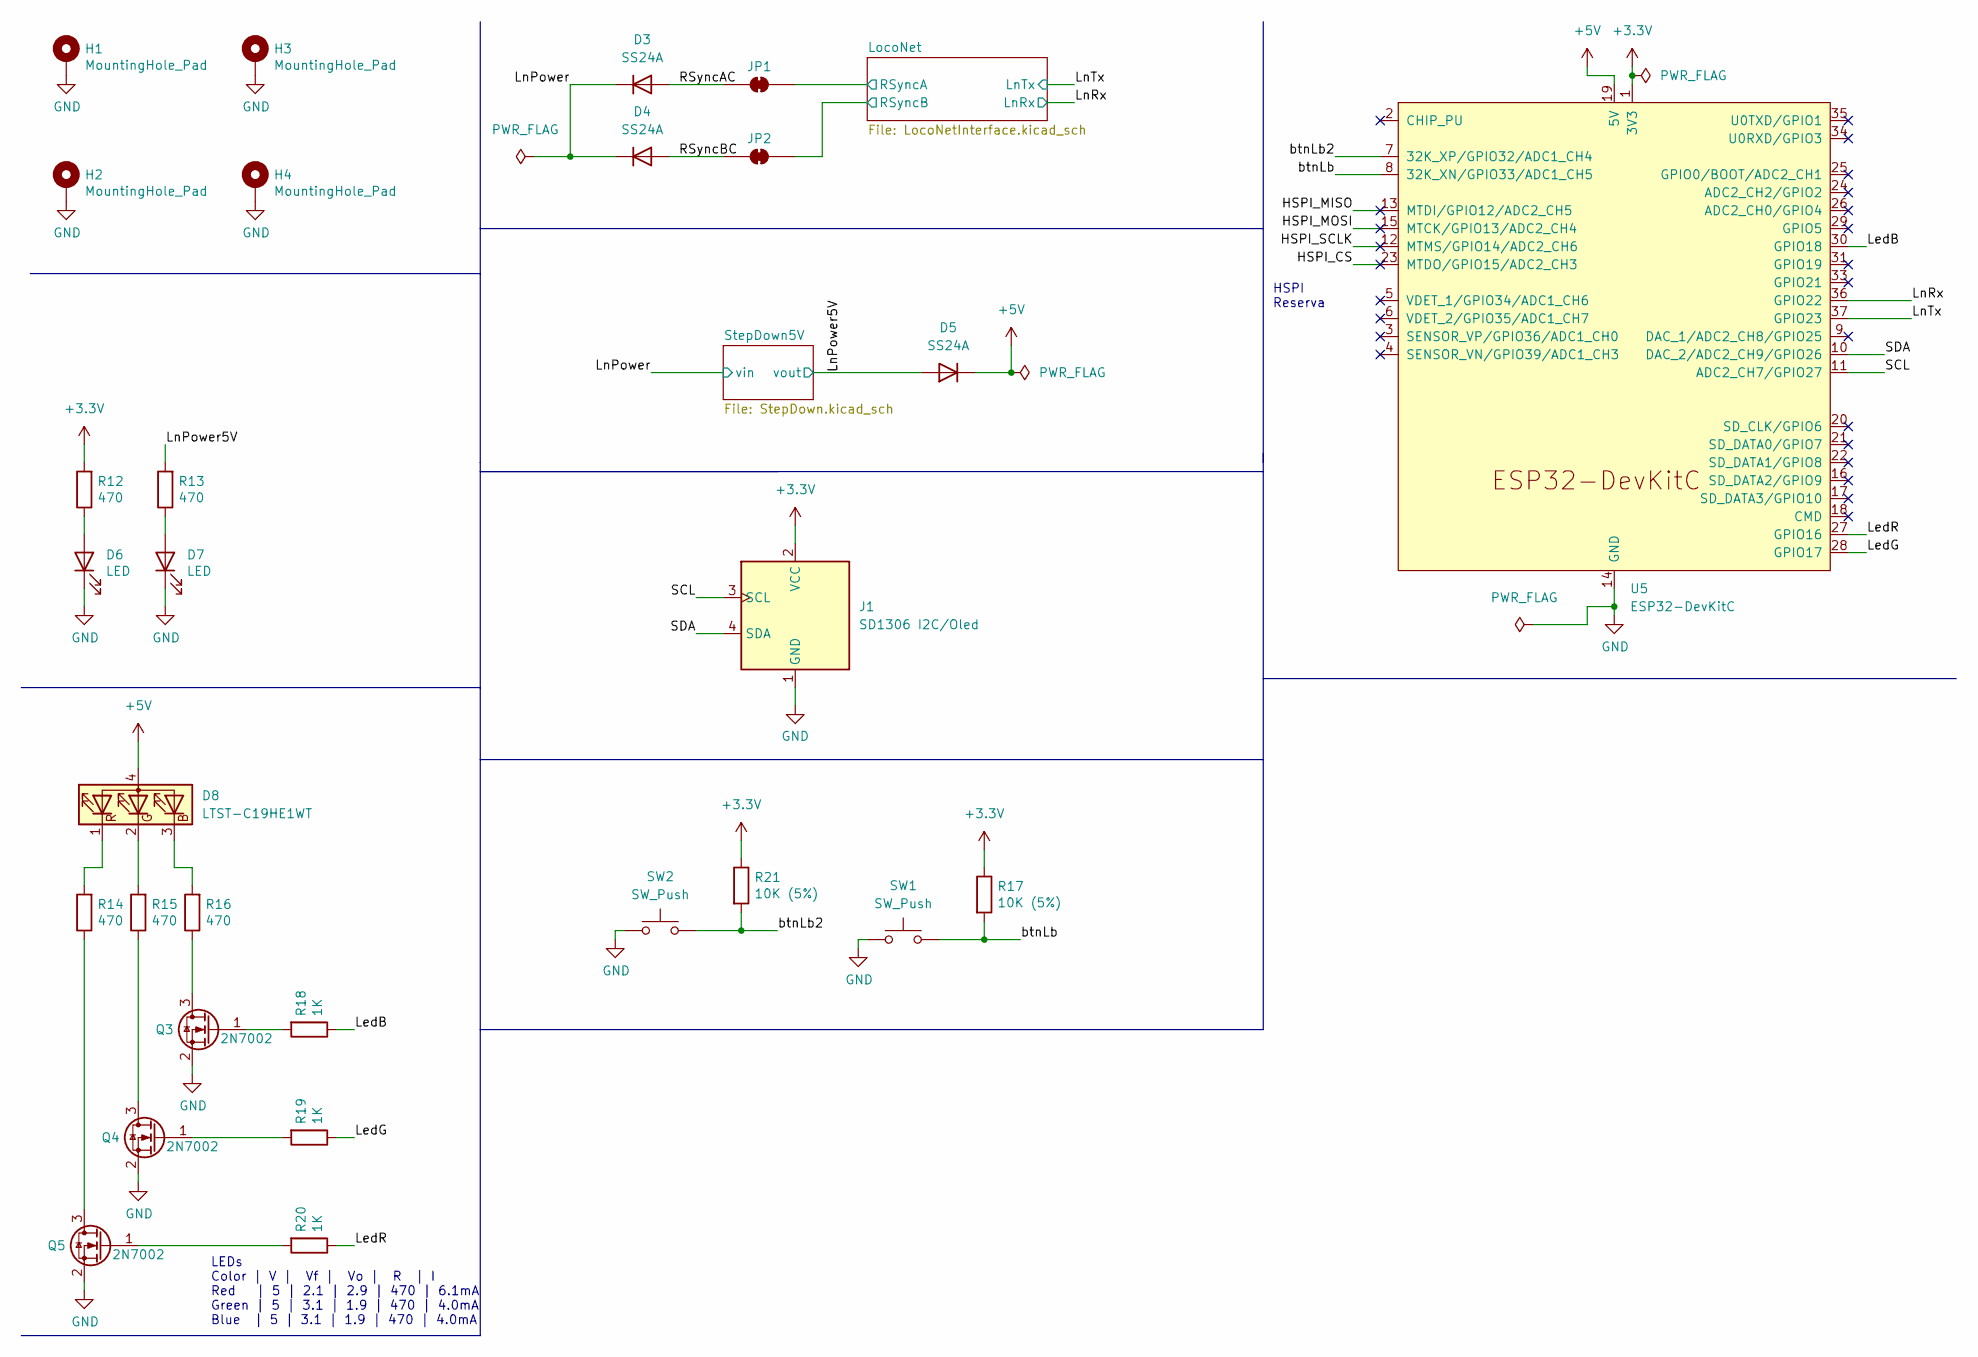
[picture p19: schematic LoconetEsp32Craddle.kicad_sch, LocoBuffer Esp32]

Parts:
D3, D4, D5: SS24A; D_SMA; LCSC C95872
D6, D7: LED; LED_0805_2012Metric; LCSC C2296
D8: LTST-C19HE1WT; LED_LiteOn_LTST-C19HE1WT; LCSC C458749
H1, H2, H3, H4: MountingHole_Pad; MountingHole_3.2mm_M3_ISO7380_Pad
J1: SD1306 I2C/Oled; ER_OLEDM0.91_1x-I2C-128x64OLED
JP1, JP2: SolderJumper_2_Bridged; SolderJumper-2_P1.3mm_Bridged2Bar_RoundedPad1.0x1.5mm
Q3, Q4, Q5: 2N7002; SOT-23; LCSC C8545
R12, R13, R14, R15, R16: 470; R_0805_2012Metric; LCSC C17710
R17, R21: 10K (5%); R_0805_2012Metric; LCSC C17414
R18, R19, R20: 1K; R_0805_2012Metric; LCSC C17513
SW1, SW2: SW_Push; SW_SPST_CK_RS282G05A3
U5: ESP32-DevKitC

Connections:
+3.3V: J1.2 (VCC), R12.2, R17.1, R21.1, U5.1 (3V3); also elsewhere on the board
+5V: D5.1 (K), D8.4 (A), U5.19 (5V)
/HSPI_CS: U5.23 (MTDO/GPIO15/ADC2_CH3)
/HSPI_MISO: U5.13 (MTDI/GPIO12/ADC2_CH5)
/HSPI_MOSI: U5.15 (MTCK/GPIO13/ADC2_CH4)
/HSPI_SCLK: U5.12 (MTMS/GPIO14/ADC2_CH6)
/LedB: R18.1, U5.30 (GPIO18)
/LedG: R19.1, U5.28 (GPIO17)
/LedR: R20.1, U5.27 (GPIO16)
/LnPower: D3.1 (K), D4.1 (K); also elsewhere on the board
/LnPower5V: D5.2 (A), R13.2; also elsewhere on the board
/LnRx: U5.36 (GPIO22); also elsewhere on the board
/LnTx: U5.37 (GPIO23); also elsewhere on the board
/LocoNet/RSyncA: JP1.2 (B); also elsewhere on the board
/LocoNet/RSyncB: JP2.2 (B); also elsewhere on the board
/RSyncAC: D3.2 (A), JP1.1 (A)
/RSyncBC: D4.2 (A), JP2.1 (A)
/SCL: J1.3 (SCL), U5.11 (ADC2_CH7/GPIO27)
/SDA: J1.4 (SDA), U5.10 (DAC_2/ADC2_CH9/GPIO26)
/btnLb: R17.2, SW1.2, U5.8 (32K_XN/GPIO33/ADC1_CH5)
/btnLb2: R21.2, SW2.2, U5.7 (32K_XP/GPIO32/ADC1_CH4)
GND: D6.1 (K), D7.1 (K), H1.1 (1_1), H2.1 (1_1), H3.1 (1_1), H4.1 (1_1), J1.1 (GND), Q3.2 (S), Q4.2 (S), Q5.2 (S), SW1.1, SW2.1, U5.14 (GND), U5.32 (GND), U5.38 (GND); also elsewhere on the board
unnamed: D6.2 (A), R12.1
unnamed: D7.2 (A), R13.1
unnamed: D8.3 (BK), R16.2
unnamed: D8.2 (GK), R15.2
unnamed: D8.1 (RK), R14.2
unnamed: Q3.3 (D), R16.1
unnamed: Q3.1 (G), R18.2
unnamed: Q4.3 (D), R15.1
unnamed: Q4.1 (G), R19.2
unnamed: Q5.3 (D), R14.1
unnamed: Q5.1 (G), R20.2

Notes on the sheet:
LEDs Color | V | Vf | Vo | R | I Red | 5 | 2.1 | 2.9 | 470 | 6.1mA Green | 5 | 3.1 | 1.9 | 470 | 4.0mA Blue | 5 | 3.1 | 1.9 | 470 | 4.0mA
HSPI Reserva

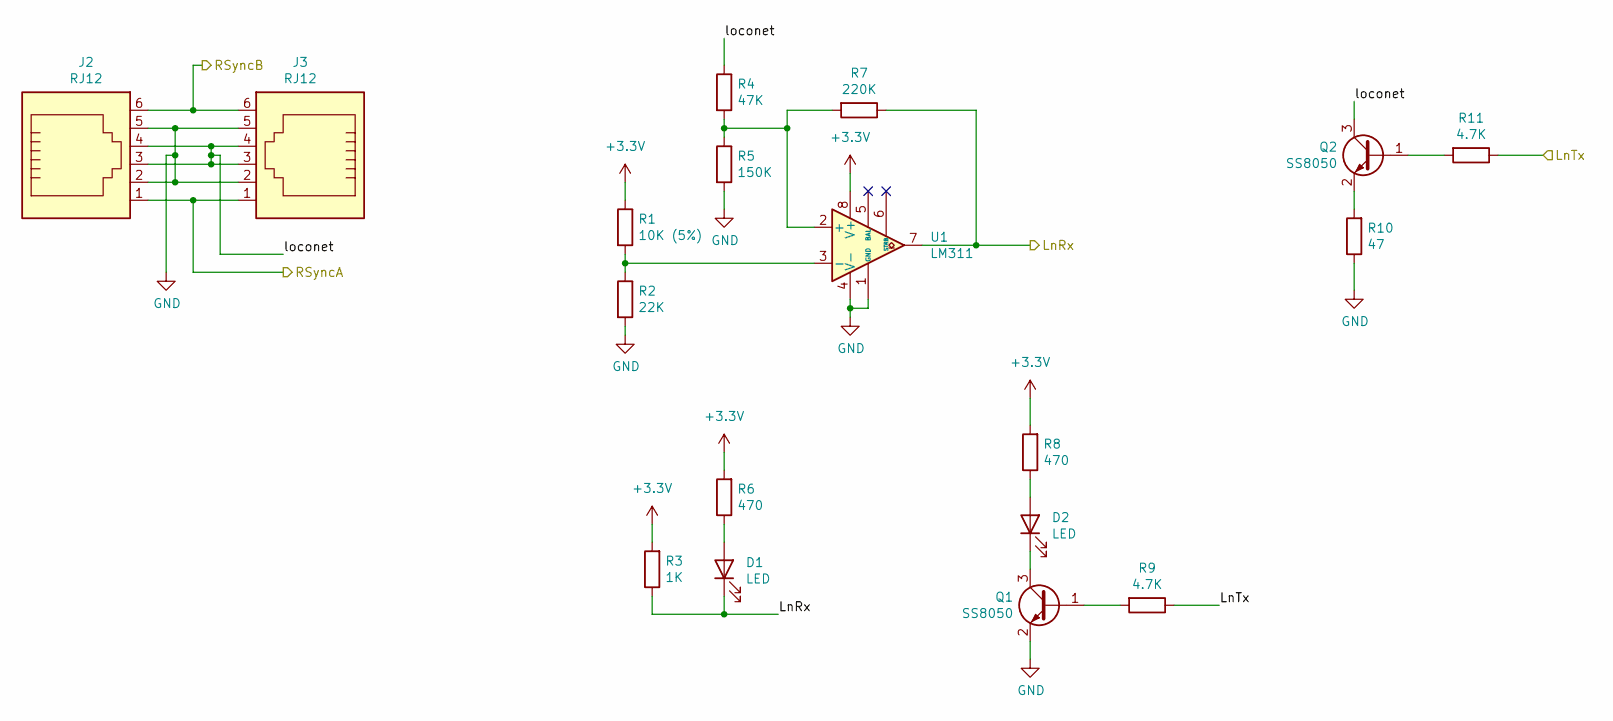
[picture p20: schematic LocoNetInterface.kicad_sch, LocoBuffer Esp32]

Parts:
D1, D2: LED; LED_0805_2012Metric; LCSC C2296
J2, J3: RJ12; RJ12_AMPHENOL_RJE0166001
Q1, Q2: SS8050; SOT-23; LCSC C2150
R1: 10K (5%); R_0805_2012Metric; LCSC C17414
R2: 22K; R_0805_2012Metric; LCSC C17560
R3: 1K; R_0805_2012Metric; LCSC C17513
R4: 47K; R_0805_2012Metric; LCSC C17713
R5: 150K; R_0805_2012Metric; LCSC C17470
R6, R8: 470; R_0805_2012Metric; LCSC C17710
R7: 220K; R_0805_2012Metric; LCSC C17556
R9, R11: 4.7K; R_0805_2012Metric; LCSC C229219
R10: 47; R_0805_2012Metric; LCSC C17714
U1: LM311; SOIC-8_3.9x4.9mm_P1.27mm; LCSC C12597

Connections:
+3.3V: R1.1, R3.2, R6.2, R8.2, U1.8 (V+); also elsewhere on the board
/LnRx: D1.1 (K), R3.1, R7.1, U1.7; also elsewhere on the board
/LnTx: R9.1, R11.1; also elsewhere on the board
/LocoNet/RSyncA: J2.1, J3.1; also elsewhere on the board
/LocoNet/RSyncB: J2.6, J3.6; also elsewhere on the board
/LocoNet/loconet: J2.3, J2.4, J3.3, J3.4, Q2.3 (C), R4.1
GND: J2.2, J2.5, J3.2, J3.5, Q1.2 (E), R2.2, R5.2, R10.1, U1.1 (GND), U1.4 (V-); also elsewhere on the board
unnamed: D1.2 (A), R6.1
unnamed: D2.2 (A), R8.1
unnamed: D2.1 (K), Q1.3 (C)
unnamed: Q1.1 (B), R9.2
unnamed: Q2.1 (B), R11.2
unnamed: Q2.2 (E), R10.2
unnamed: R4.2, R5.1, R7.2, U1.2 (+)
unnamed: R1.2, R2.1, U1.3 (-)

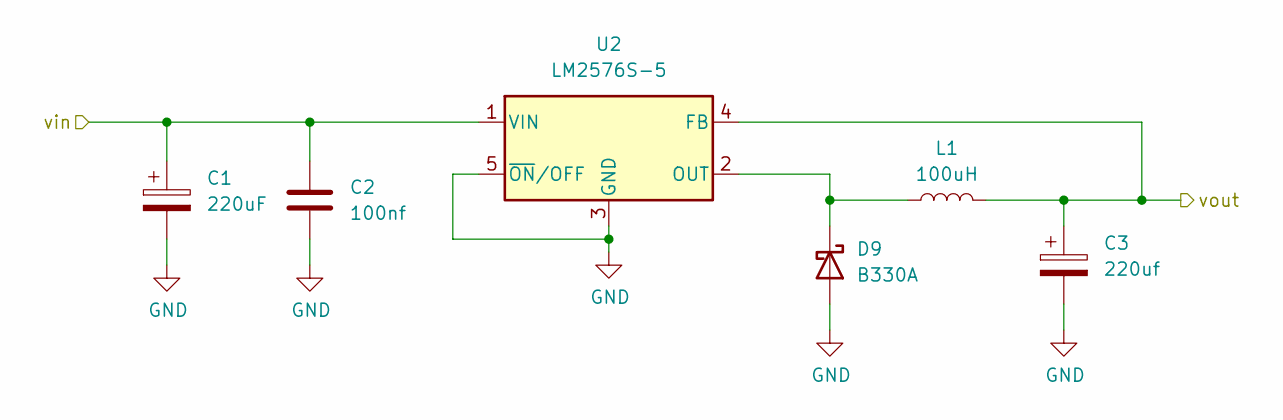
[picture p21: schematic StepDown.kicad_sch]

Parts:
C1: 220uF; CP_Elec_8x10.5; LCSC C131124
C2: 100nf; C_0805_2012Metric; LCSC C282732
C3: 220uf; CP_Elec_8x10.5; LCSC C131124
D9: B330A; D_SMA; LCSC C110485
L1: 100uH; L_Sunlord_MWSA1206S-101; LCSC C408533
U2: LM2576S-5; TO-263-5_TabPin3; LCSC C194472

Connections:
/LnPower: C1.1, C2.1, U2.1 (VIN); also elsewhere on the board
/LnPower5V: C3.1, L1.2, U2.4 (FB); also elsewhere on the board
GND: C1.2, C2.2, C3.2, D9.2 (A), U2.3 (GND), U2.5 (~ON/OFF); also elsewhere on the board
unnamed: D9.1 (K), L1.1, U2.2 (OUT)

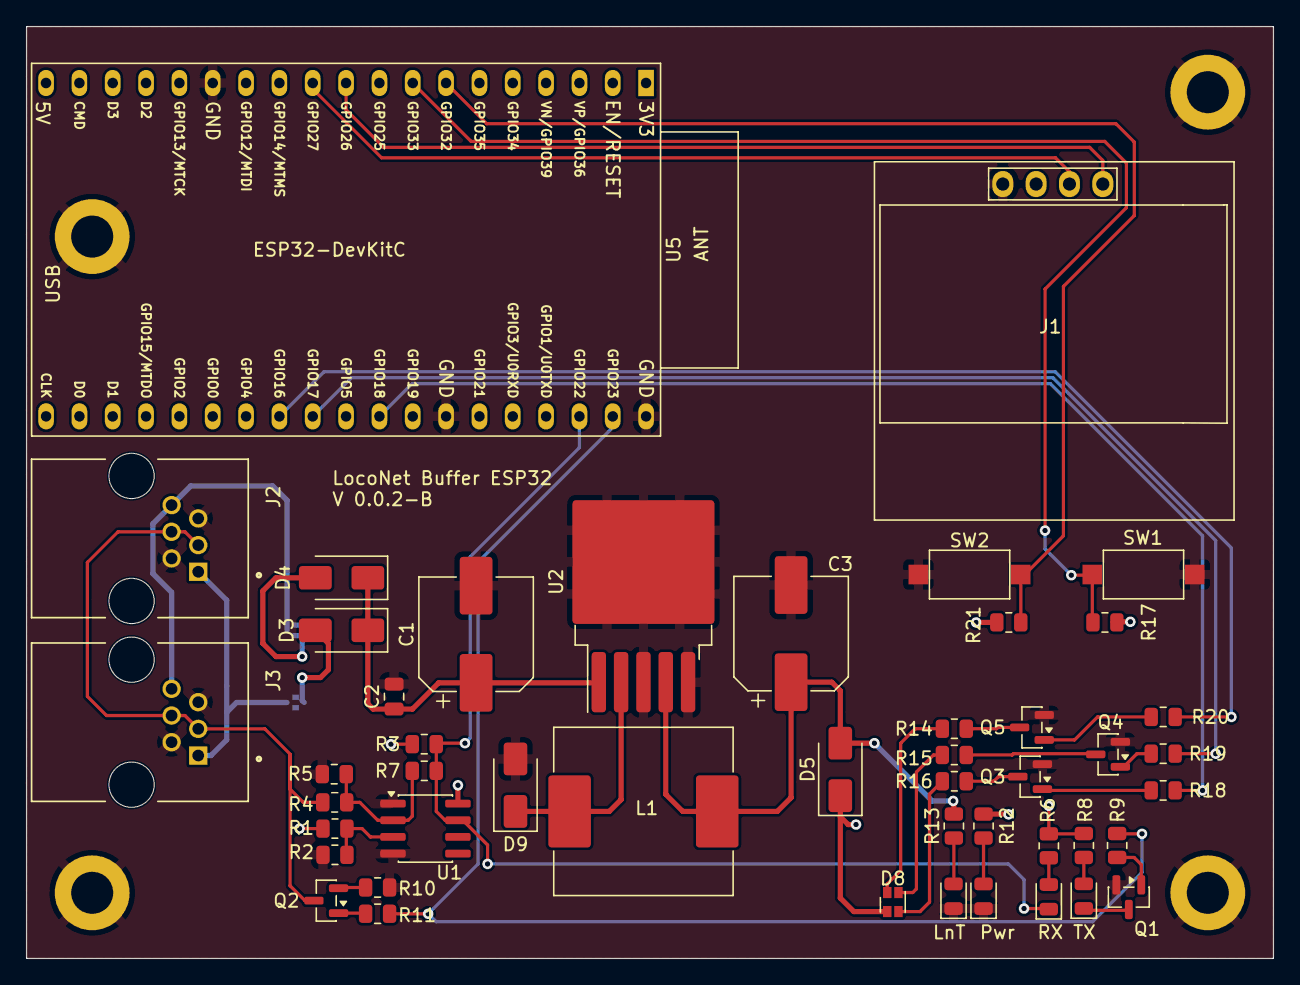
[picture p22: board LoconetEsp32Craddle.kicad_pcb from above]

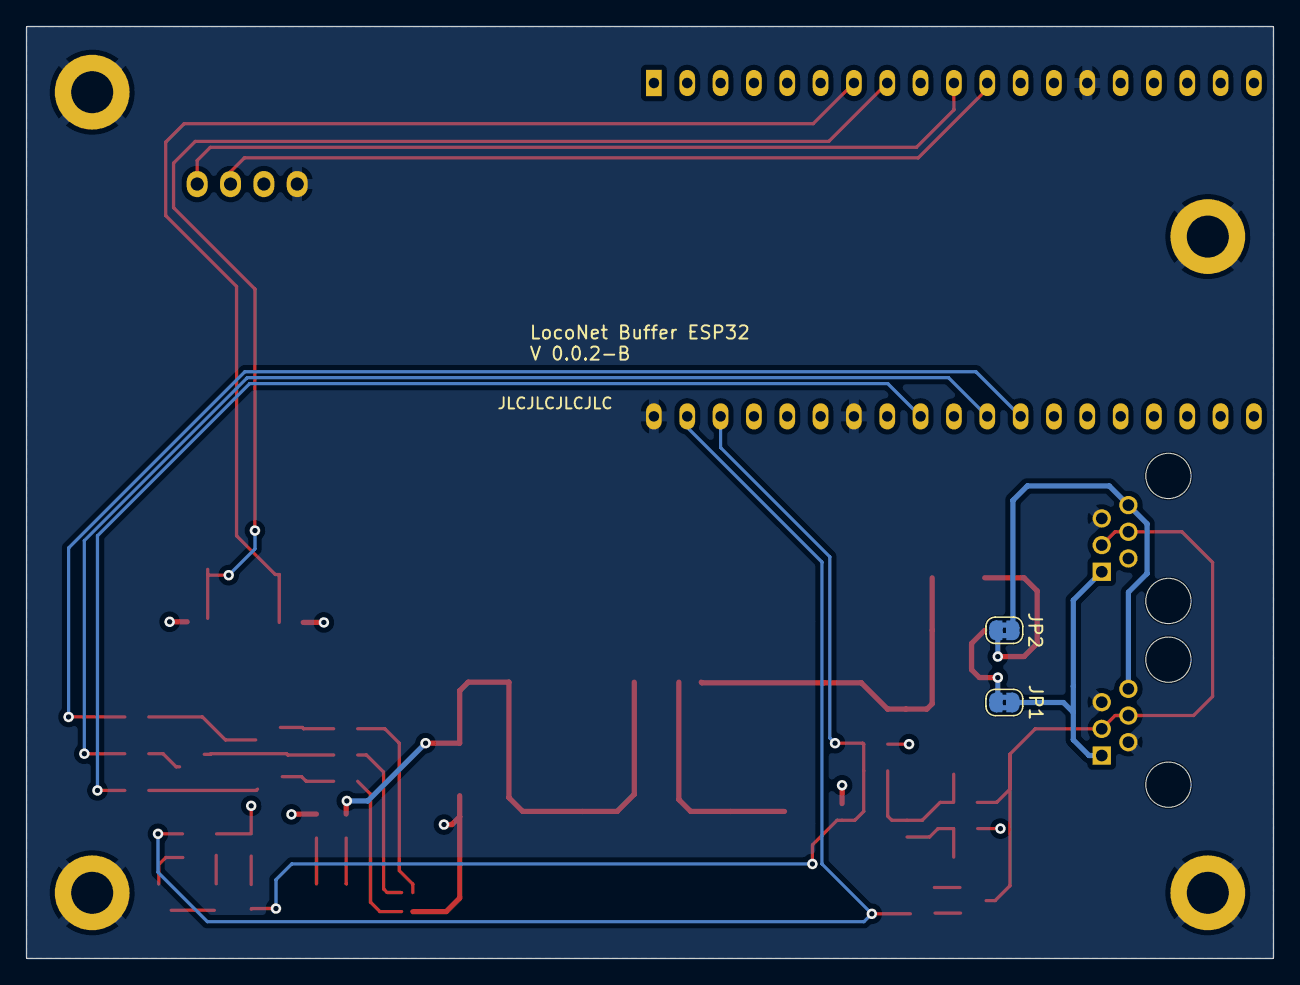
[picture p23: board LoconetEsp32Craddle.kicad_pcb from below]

Board: 4 copper layers, 95.0 x 71.0 mm, 53 parts (2 on the bottom side), 39 nets.

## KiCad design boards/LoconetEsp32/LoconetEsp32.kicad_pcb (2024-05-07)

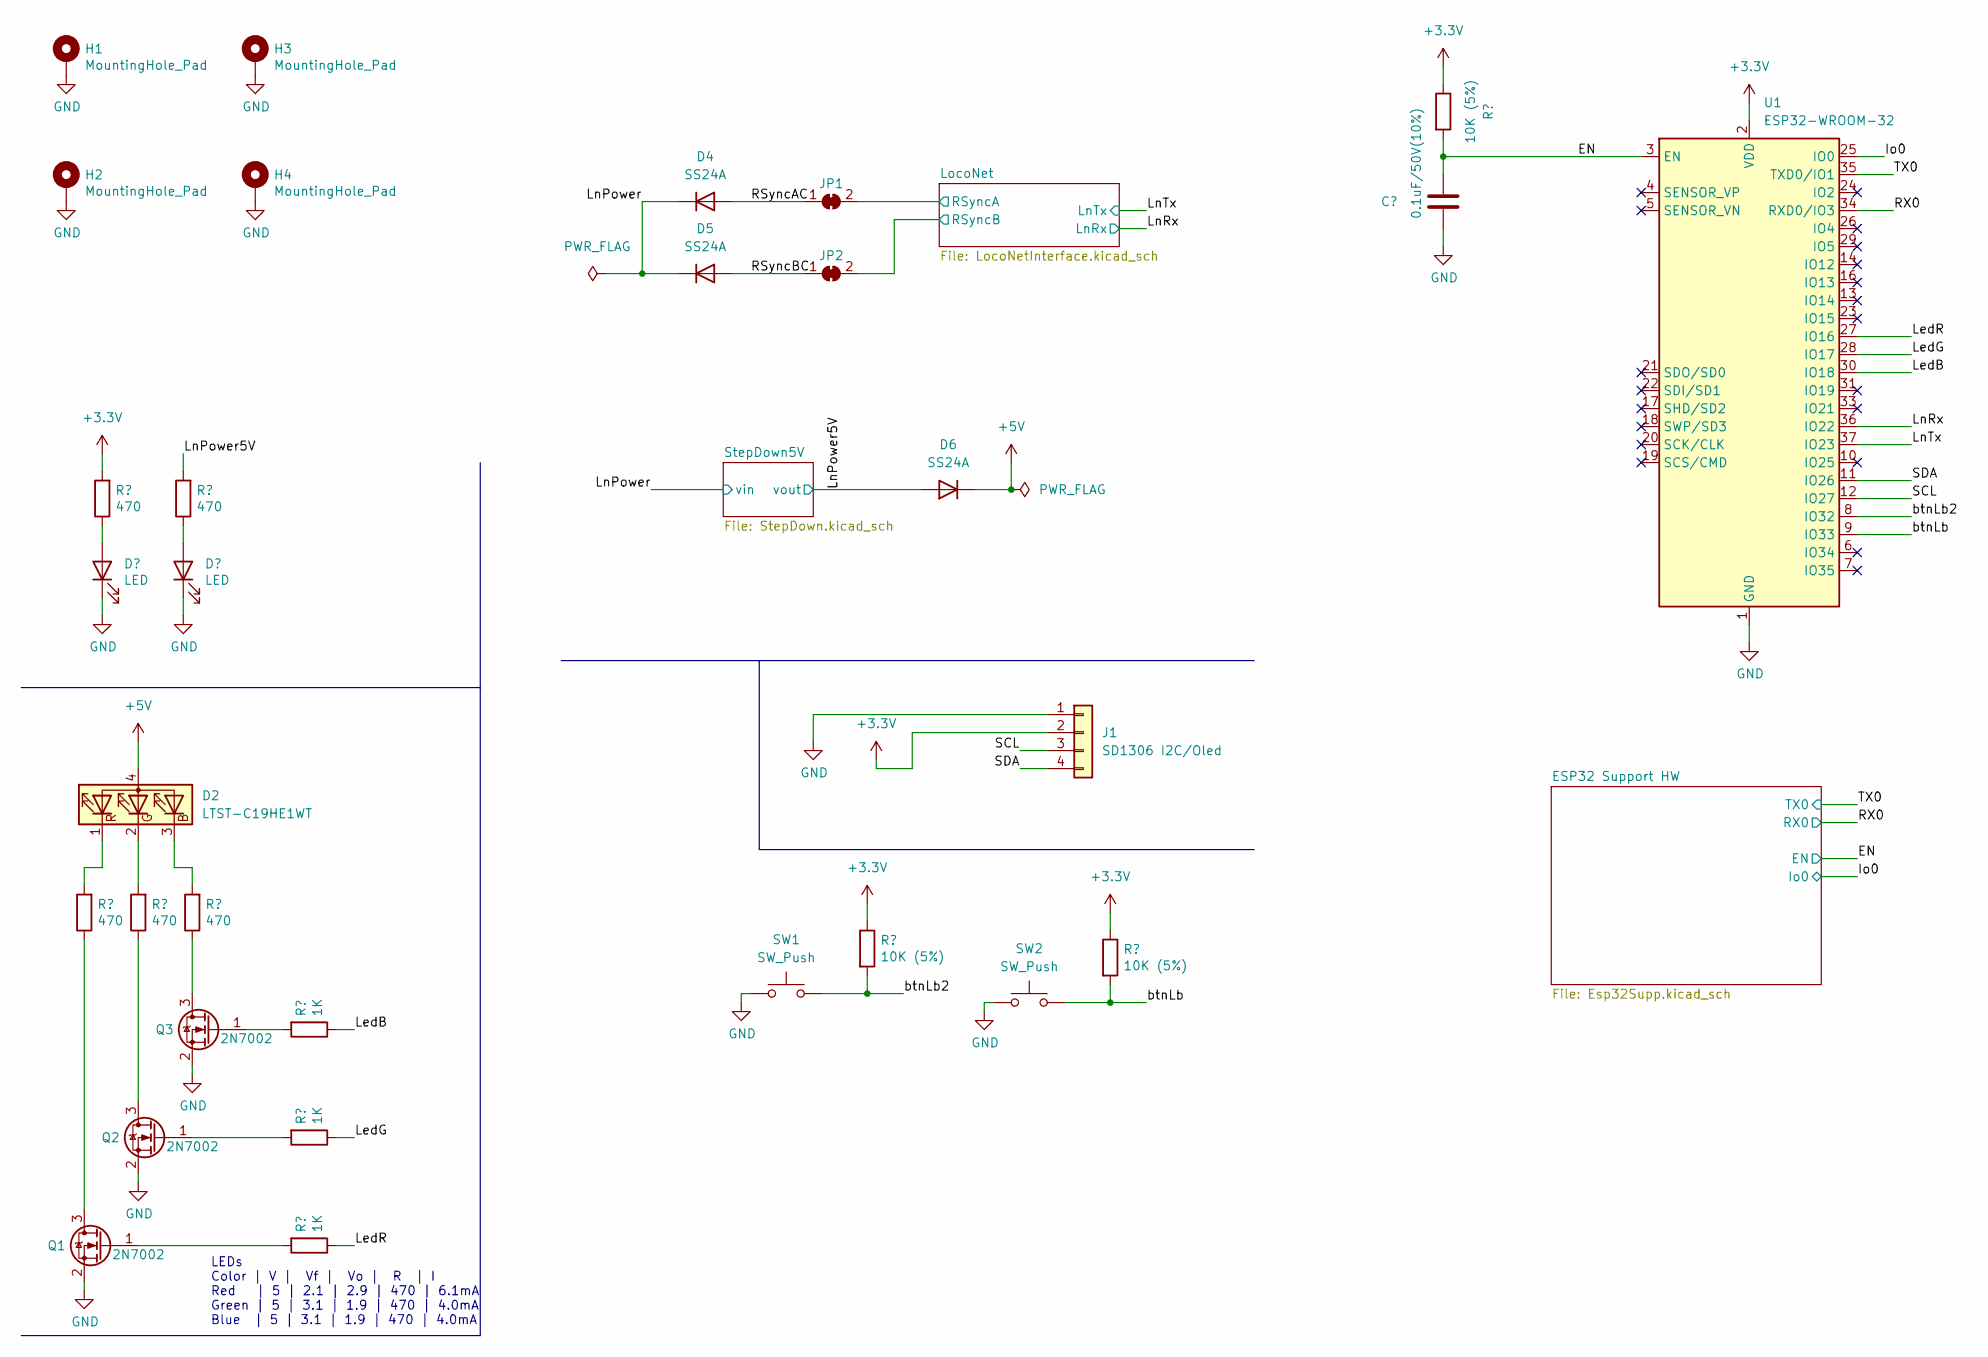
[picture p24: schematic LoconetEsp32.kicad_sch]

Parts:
C1: 0.1uF/50V(10%); C_0805_2012Metric; LCSC C49678
D1, D3: LED; LED_0805_2012Metric; LCSC C2296
D2: LTST-C19HE1WT; LED_LiteOn_LTST-C19HE1WT; LCSC C458749
D4, D5, D6: SS24A; D_SMA; LCSC C95872
H1, H2, H3, H4: MountingHole_Pad; MountingHole_3.2mm_M3_ISO7380_Pad
J1: SD1306 I2C/Oled; 128x64OLED
JP1, JP2: SolderJumper_2_Bridged; SolderJumper-2_P1.3mm_Bridged2Bar_RoundedPad1.0x1.5mm
Q1, Q2, Q3: 2N7002; SOT-23; LCSC C8545
R1, R2, R3, R4, R5: 470; R_0805_2012Metric; LCSC C17710
R6, R7, R8: 1K; R_0805_2012Metric; LCSC C17513
R9, R10, R11: 10K (5%); R_0805_2012Metric; LCSC C17414
SW1, SW2: SW_Push; SW_SPST_CK_RS282G05A3
U1: ESP32-WROOM-32; LCSC C701343

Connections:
+3.3V: J1.2, R2.2, R9.1, R10.1, R11.1, U1.2 (VDD); also elsewhere on the board
+5V: D2.4 (A), D6.1 (K); also elsewhere on the board
/EN: C1.1, R11.2, U1.3 (EN); also elsewhere on the board
/Io0: U1.25 (IO0); also elsewhere on the board
/LedB: R6.1, U1.30 (IO18)
/LedG: R7.1, U1.28 (IO17)
/LedR: R8.1, U1.27 (IO16)
/LnPower: D4.1 (K), D5.1 (K); also elsewhere on the board
/LnPower5V: D6.2 (A), R4.2; also elsewhere on the board
/LnRx: U1.36 (IO22); also elsewhere on the board
/LnTx: U1.37 (IO23); also elsewhere on the board
/LocoNet/RSyncA: JP1.2 (B); also elsewhere on the board
/LocoNet/RSyncB: JP2.2 (B); also elsewhere on the board
/RSyncAC: D4.2 (A), JP1.1 (A)
/RSyncBC: D5.2 (A), JP2.1 (A)
/RX0: U1.34 (RXD0/IO3); also elsewhere on the board
/SCL: J1.3, U1.12 (IO27)
/SDA: J1.4, U1.11 (IO26)
/TX0: U1.35 (TXD0/IO1); also elsewhere on the board
/btnLb: R10.2, SW2.2, U1.9 (IO33)
/btnLb2: R9.2, SW1.2, U1.8 (IO32)
GND: C1.2, D1.1 (K), D3.1 (K), H1.1, H2.1, H3.1, H4.1, J1.1, Q1.2 (S), Q2.2 (S), Q3.2 (S), SW1.1, SW2.1, U1.1 (GND), U1.15 (GND), U1.38 (GND), U1.39 (GND); also elsewhere on the board
unnamed: D1.2 (A), R2.1
unnamed: D2.3 (BK), R5.2
unnamed: D2.2 (GK), R3.2
unnamed: D2.1 (RK), R1.2
unnamed: D3.2 (A), R4.1
unnamed: Q1.3 (D), R1.1
unnamed: Q1.1 (G), R8.2
unnamed: Q2.3 (D), R3.1
unnamed: Q2.1 (G), R7.2
unnamed: Q3.3 (D), R5.1
unnamed: Q3.1 (G), R6.2

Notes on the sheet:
LEDs Color | V | Vf | Vo | R | I Red | 5 | 2.1 | 2.9 | 470 | 6.1mA Green | 5 | 3.1 | 1.9 | 470 | 4.0mA Blue | 5 | 3.1 | 1.9 | 470 | 4.0mA

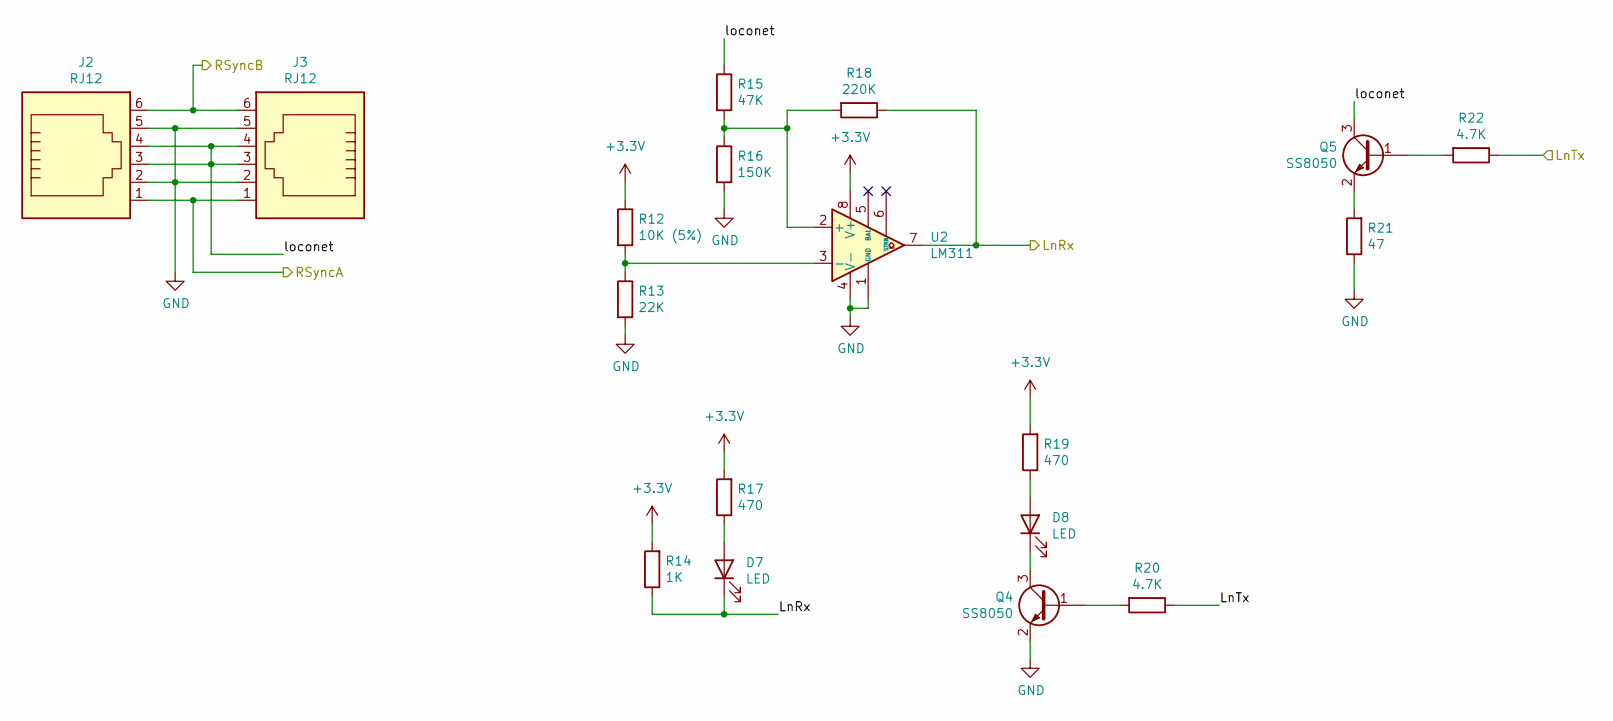
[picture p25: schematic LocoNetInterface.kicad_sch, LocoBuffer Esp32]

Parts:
D7, D8: LED; LED_0805_2012Metric; LCSC C2296
J2, J3: RJ12; AMPHENOL_RJE0166001
Q4, Q5: SS8050; SOT-23; LCSC C2150
R12: 10K (5%); R_0805_2012Metric; LCSC C17414
R13: 22K; R_0805_2012Metric; LCSC C17560
R14: 1K; R_0805_2012Metric; LCSC C17513
R15: 47K; R_0805_2012Metric; LCSC C17713
R16: 150K; R_0805_2012Metric; LCSC C17470
R17, R19: 470; R_0805_2012Metric; LCSC C17710
R18: 220K; R_0805_2012Metric; LCSC C17556
R20, R22: 4.7K; R_0805_2012Metric; LCSC C229219
R21: 47; R_0805_2012Metric; LCSC C17714
U2: LM311; SOIC-8_3.9x4.9mm_P1.27mm; LCSC C12597

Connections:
+3.3V: R12.1, R14.2, R17.2, R19.2, U2.8 (V+); also elsewhere on the board
/LnRx: D7.1 (K), R14.1, R18.1, U2.7; also elsewhere on the board
/LnTx: R20.1, R22.1; also elsewhere on the board
/LocoNet/RSyncA: J2.1, J3.1; also elsewhere on the board
/LocoNet/RSyncB: J2.6, J3.6; also elsewhere on the board
/LocoNet/loconet: J2.3, J2.4, J3.3, J3.4, Q5.3 (C), R15.1
GND: J2.2, J2.5, J3.2, J3.5, Q4.2 (E), R13.2, R16.2, R21.1, U2.1 (GND), U2.4 (V-); also elsewhere on the board
unnamed: D7.2 (A), R17.1
unnamed: D8.2 (A), R19.1
unnamed: D8.1 (K), Q4.3 (C)
unnamed: Q4.1 (B), R20.2
unnamed: Q5.1 (B), R22.2
unnamed: Q5.2 (E), R21.2
unnamed: R15.2, R16.1, R18.2, U2.2 (+)
unnamed: R12.2, R13.1, U2.3 (-)

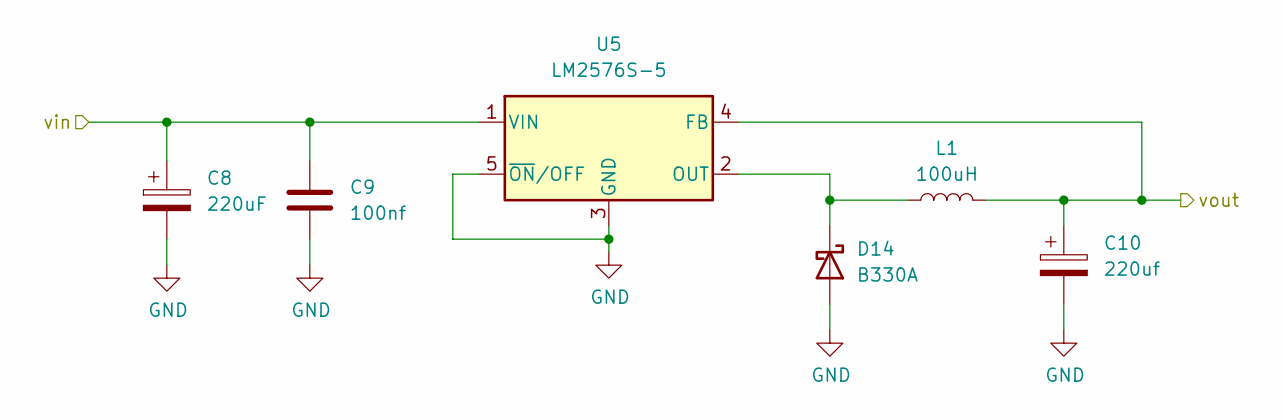
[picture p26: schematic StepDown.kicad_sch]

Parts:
C8: 220uF; CP_Elec_8x10.5; LCSC C131124
C9: 100nf; C_0805_2012Metric; LCSC C282732
C10: 220uf; CP_Elec_8x10.5; LCSC C131124
D14: B330A; D_SMA; LCSC C110485
L1: 100uH; L_Sunlord_MWSA1206S-101; LCSC C408533
U5: LM2576S-5; TO-263-5_TabPin3; LCSC C194472

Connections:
/LnPower: C8.1, C9.1, U5.1 (VIN); also elsewhere on the board
/LnPower5V: C10.1, L1.2, U5.4 (FB); also elsewhere on the board
GND: C8.2, C9.2, C10.2, D14.2 (A), U5.3 (GND), U5.5 (~ON/OFF); also elsewhere on the board
unnamed: D14.1 (K), L1.1, U5.2 (OUT)

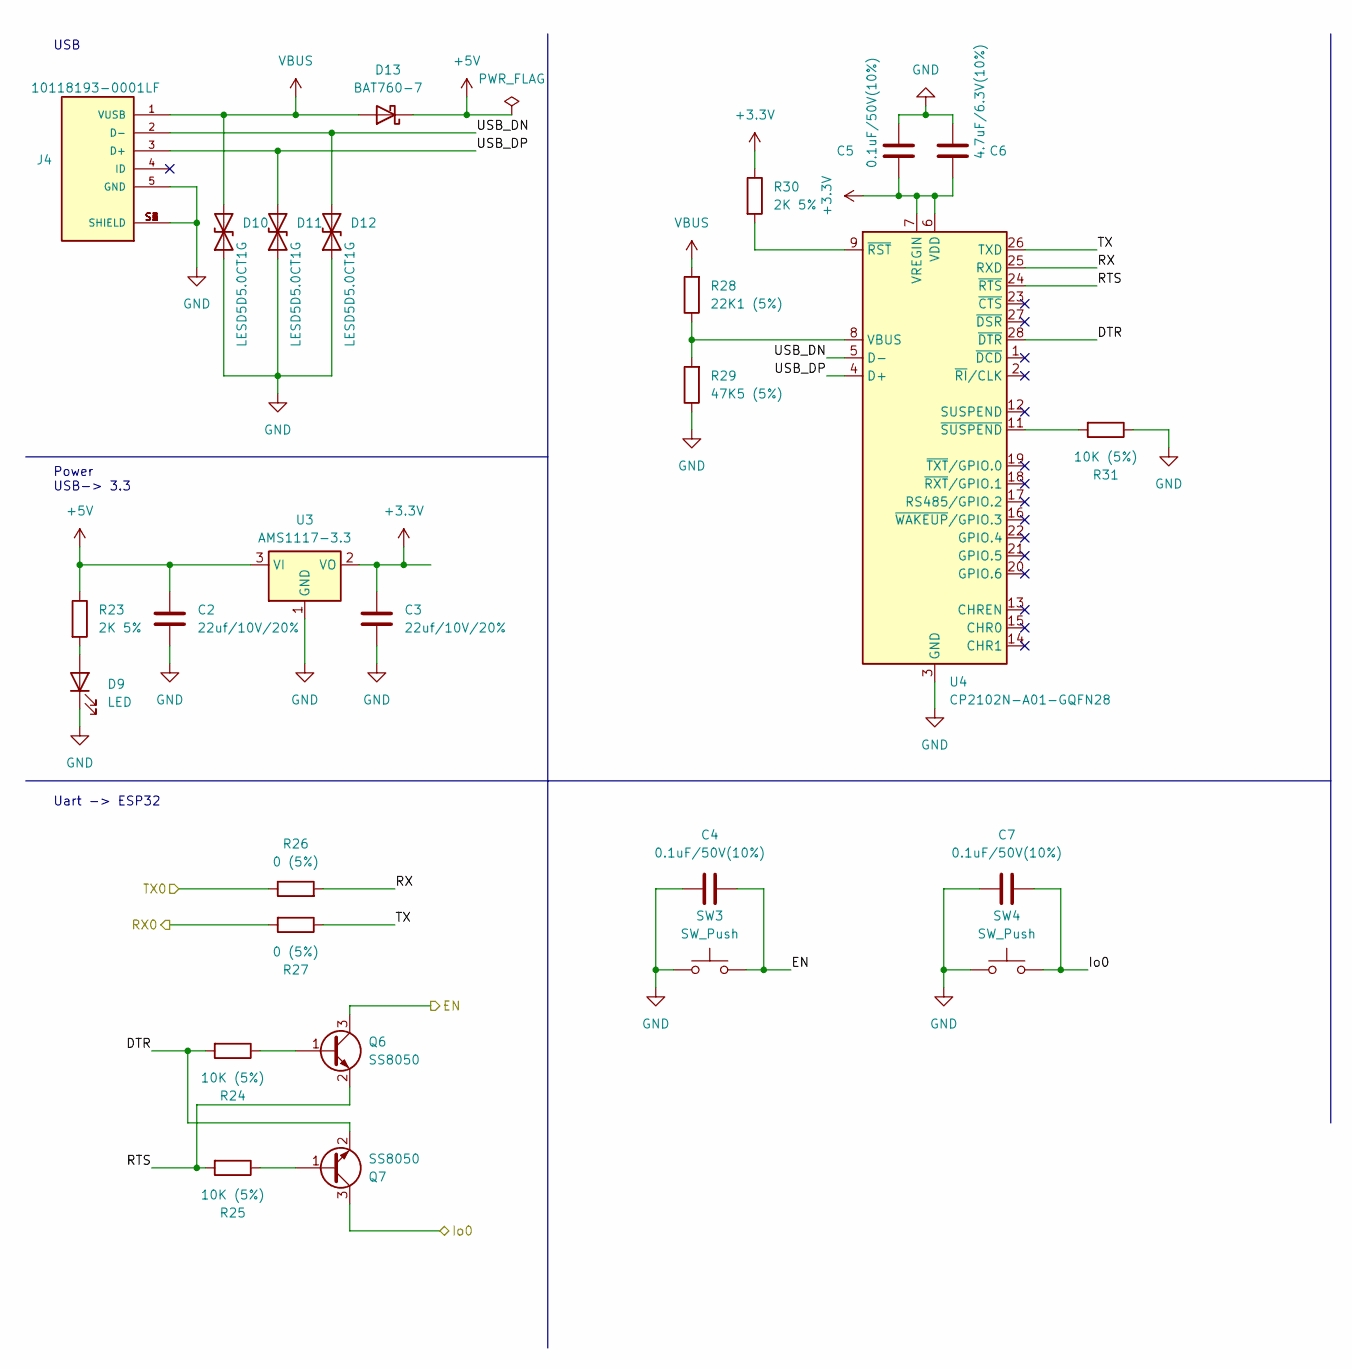
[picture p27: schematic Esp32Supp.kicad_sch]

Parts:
C2, C3: 22uf/10V/20%; C_0805_2012Metric; LCSC C45783
C4, C5, C7: 0.1uF/50V(10%); C_0805_2012Metric; LCSC C49678
C6: 4.7uF/6.3V(10%); C_0805_2012Metric; LCSC C1779
D9: LED; LED_0805_2012Metric; LCSC C2296
D10, D11, D12: LESD5D5.0CT1G; D_SOD-523; LCSC C383211
D13: BAT760-7; D_SOD-323; LCSC C124187
J4: 10118193-0001LF; AMPHENOL_10118193-0001LF; PARTREV E; LCSC C132562
Q6, Q7: SS8050; SOT-23; LCSC C2150
R23, R30: 2K 5%; R_0805_2012Metric; LCSC C212449
R24, R25, R31: 10K (5%); R_0805_2012Metric; LCSC C17414
R26, R27: 0 (5%); R_0805_2012Metric; LCSC C2936632
R28: 22K1 (5%); R_0805_2012Metric; LCSC C153391
R29: 47K5 (5%); R_0805_2012Metric; LCSC C245335
SW3, SW4: SW_Push; SW_SPST_CK_RS282G05A3
U3: AMS1117-3.3; SOT-223-3_TabPin2; LCSC C6186
U4: CP2102N-A01-GQFN28; QFN-28-1EP_5x5mm_P0.5mm_EP3.35x3.35mm; LCSC C964632

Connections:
+3.3V: C3.1, C5.2, C6.2, R30.1, U3.2 (VO), U4.6 (VDD), U4.7 (VREGIN); also elsewhere on the board
+5V: C2.1, D13.1 (K), R23.1, U3.3 (VI); also elsewhere on the board
/EN: C4.2, Q6.3 (C), SW3.2; also elsewhere on the board
/ESP32 Support HW/DTR: Q7.2 (E), R24.2, U4.28 (~DTR)
/ESP32 Support HW/RTS: Q6.2 (E), R25.2, U4.24 (~RTS)
/ESP32 Support HW/RX: R26.2, U4.25 (RXD)
/ESP32 Support HW/TX: R27.1, U4.26 (TXD)
/ESP32 Support HW/USB_DN: D12.2 (A2), J4.2 (D-), U4.5 (D-)
/ESP32 Support HW/USB_DP: D11.2 (A2), J4.3 (D+), U4.4 (D+)
/Io0: C7.2, Q7.3 (C), SW4.2; also elsewhere on the board
/RX0: R27.2; also elsewhere on the board
/TX0: R26.1; also elsewhere on the board
GND: C2.2, C3.2, C4.1, C5.1, C6.1, C7.1, D9.1 (K), D10.1 (A1), D11.1 (A1), D12.1 (A1), J4.5 (GND), J4.S1 (SHIELD), J4.S2 (SHIELD), J4.S3 (SHIELD), J4.S4 (SHIELD), J4.S5 (SHIELD), J4.S6 (SHIELD), R29.1, R31.1, SW3.1, SW4.1, U3.1 (GND), U4.3 (GND), U4.29 (GND); also elsewhere on the board
unnamed: D9.2 (A), R23.2
unnamed: Q6.1 (B), R24.1
unnamed: Q7.1 (B), R25.1
unnamed: R28.1, R29.2, U4.8 (VBUS)
unnamed: R30.2, U4.9 (~RST)
unnamed: R31.2, U4.11 (~SUSPEND)
VBUS: D10.2 (A2), D13.2 (A), J4.1 (VUSB), R28.2

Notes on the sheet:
Power USB-> 3.3
Uart -> ESP32
USB

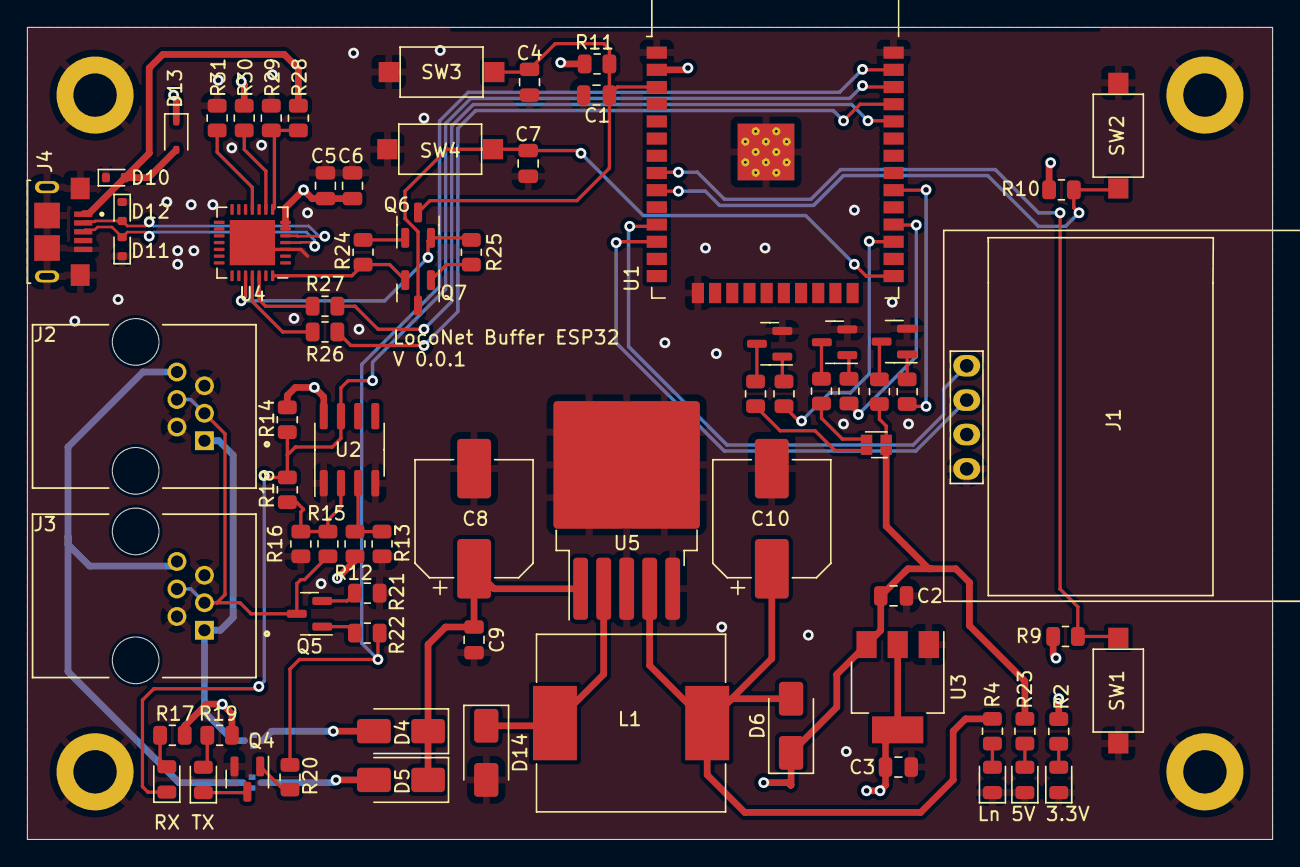
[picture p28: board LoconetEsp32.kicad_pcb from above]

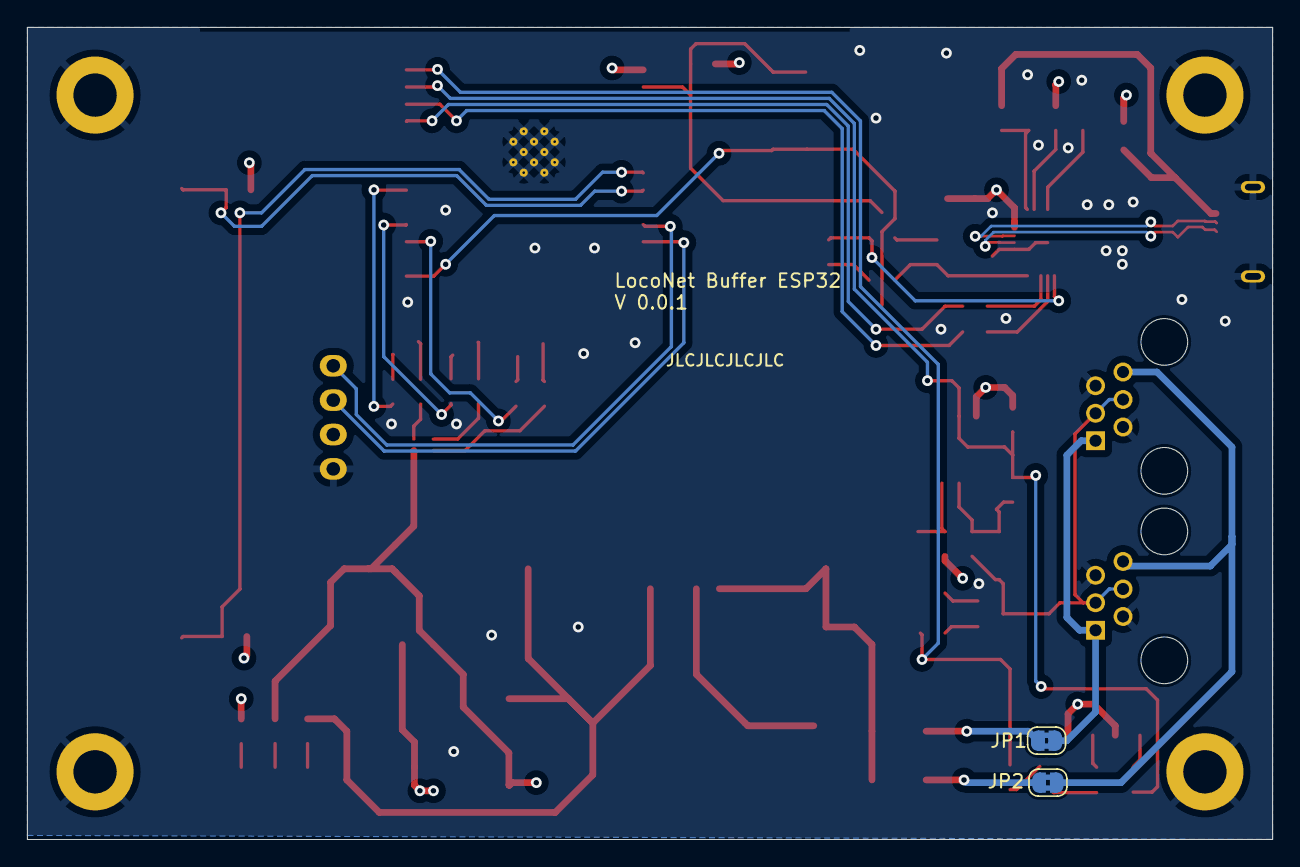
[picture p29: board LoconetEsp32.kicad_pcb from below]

Board: 4 copper layers, 92.0 x 60.0 mm, 82 parts (2 on the bottom side), 56 nets.

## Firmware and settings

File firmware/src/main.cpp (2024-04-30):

#include <Arduino.h>
#include <IoTT_LocoNetHBESP32.h> 
#include <IoTT_lbServer.h>

#include "lbWifi.h"
#include "WebServer.h"
#include "lbLcd.h"
#include "loconet.h"




LocoNetESPSerial lnSerial(2); //true is inverted signals
IoTT_LBServer * lbServer=NULL;
IoTT_DigitraxBuffers * digitraxBuffer = NULL;
std::vector<wsClientInfo> globalClients; 
String deviceName="Esp32LB";


//used for performance analysis
#ifdef showPerformance
  uint16_t loopCtr = 0;
  uint32_t myTimer = millis() + 1000;
#endif



void setup() {
  // put your setup code here, to run once:
  pinMode(BTN,INPUT_PULLUP);
  pinMode(PIN_CFG,INPUT);
  pinMode(PIN_LED,OUTPUT);
  pinMode(LED_R,OUTPUT);
  pinMode(LED_G,OUTPUT);
  pinMode(LED_B,OUTPUT);
  digitalWrite(LED_R,0);
  digitalWrite(LED_G,0);
  digitalWrite(LED_B,0); 
  initLcd();

  Serial.begin(115200); 
  lnSerial.setBusyLED(LED_R);
  lnSerial.begin(pinRx,pinTx,false,true);
  pinMode(LED_R,OUTPUT);
  digitalWrite(LED_R,1);
  digitalWrite(LED_R,0);

  //while (!Serial);
  initWifi();  
  digitraxBuffer = new IoTT_DigitraxBuffers(sendMsg);
  lbServer=new IoTT_LBServer();
  lbServer->initLBServer(true);
  lbServer->initMDNS();
  MDNS.addService("http","tcp",80);
  MDNS.addService("locobuffer","tcp",1234);
  delay(1000);
  
  lbServer->startServer();
  initWebServer();
  Serial.println("Init Done");

  randomSeed((uint32_t)ESP.getEfuseMac()); //initialize random generator with MAC
}

void loop() {
  // put your main code here, to run repeatedly:

#ifdef showPerformance
  loopCtr++;
  if (millis() > myTimer)
  {
    Serial.printf("Timer Loop: %i\n", loopCtr);
    loopCtr = 0;
    myTimer += 1000;
  }
#endif
  lnSerial.processLoop();
  lbServer->processLoop();
  LCD_update_loop();
  yield();
}

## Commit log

2024-04-30 Import Docs from original Repo
    [LM2576S-5.0.xlsx]
2024-04-30 Import of Boards
    [Esp32Supp.kicad_sch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]
2024-04-30 Change name to match folder
    [LoconetEsp32.kicad_pcb, LoconetEsp32.kicad_sch]
2024-05-07 Updated to kicad 8
    [Esp32Supp.kicad_sch, LocoNetInterface.kicad_sch, LoconetEsp32.kicad_pcb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]
2026-06-20 Update a Kicad 10 y eliminacion ERC
    [Esp32Supp.kicad_sch, LocoNetInterface.kicad_sch, LoconetEsp32Craddle.kicad_pcb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]
2026-06-20 Update PCB
    [LoconetEsp32Craddle.kicad_pcb]
2026-06-20 Docu Kibot 10
    [LocoBuffer-B_Cu.gbr, LocoBuffer-B_Mask.gbr, LocoBuffer-B_Silkscreen.gbr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]
